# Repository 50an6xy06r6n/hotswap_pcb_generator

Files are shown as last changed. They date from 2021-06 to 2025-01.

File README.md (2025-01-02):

# 3D-Printable Hotswap Keyboard PCB Generator
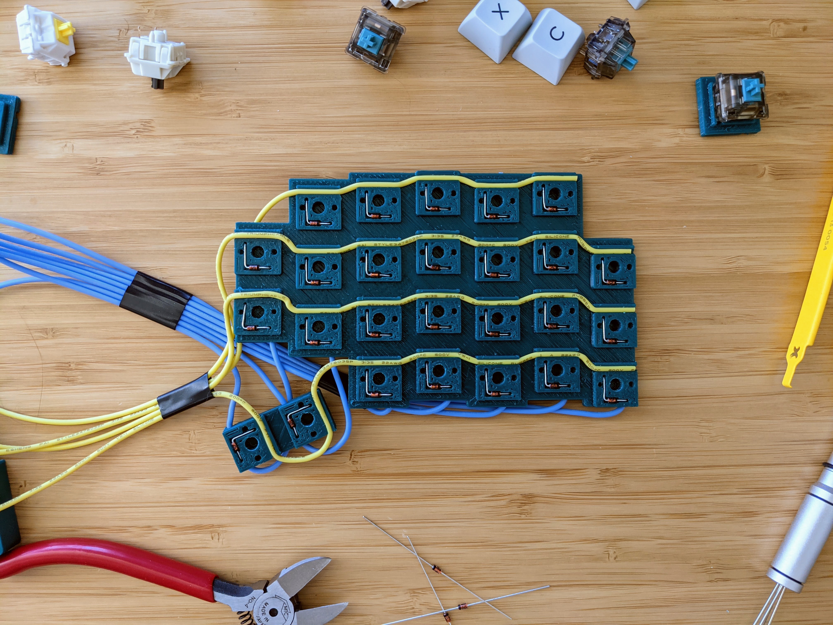
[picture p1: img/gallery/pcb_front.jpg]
Example PCB


This is an OpenSCAD script that can be used to generate 3D-printable hotswap "PCBs", plates, and cases for prototyping new keyboard layouts. I originally wrote this to help me prototype a split ergo layout without needing to solder/desolder all the switches every time. If you're only going to be building the keyboard once, this is probably a lot more work than just handwiring, but it might be useful if you're iterating on a design and want to reuse your switches easily. Currently supports MX and Kailh Choc v1 switches. If someone wants to send me low-profile Cherry switches, v2 Chocs, or Alps I can add those as well.

### Features
- Support for MX-style and Kailh Choc switches
- Automatically generate plates from the same layout data
- Generate cases with tenting options
- Integrate microcontrollers and TRRS sockets for a fully-functional keyboard
- Support for stabilizers
- Support for non-standard grid spacings

### Usage
The OpenSCAD script reads the layout data from the `layout.scad` header file, which you can either write by hand or generate from a KLE json file using the provided script (requires node.js 14+):
```
cd script/
npm install
npm start -- <layout json file>
```
Once the basic layout is set there are more values you can tweak in `layout.scad` to change the footprint of the PCB, add components like MCU/TRRS sockets, and add stabilizers/standoffs. Other parameters such as wire/pin diameters and pcb/plate thicknesses (and many many more) are contained in `parameters.scad`. All these values are described in full in the [`scad/` README](scad/README.md). [`default_layout.scad`](scad/default_layout.scad) contains an example layout that uses most of the available customizations, so you can see what's possible. The [`example_layouts/`](example_layouts) directory contains a couple of other examples as well, with varying degrees of complexity.

**Note on OpenSCAD:** I highly recommend installing [the nightly development build of OpenSCAD](https://openscad.org/downloads.html#snapshots), as it includes support for the [Manifold](https://github.com/elalish/manifold) geometry engine, which is much much faster than the CGAL library that OpenSCAD has historically used. Stuff that can take minutes to render with CGAL renders in seconds with Manifold enabled. It can be enabled in the nightly builds by going to Edit -> Preferences -> Features and checking the box for "manifold". While you're in there you might also want to enable "roof" as well, since it's used for some of the (experimental) chamfering options.

### Assembly
The [full build guide](guide/build_guide.md) goes into much more details and has pictures of the process, but here's how assembly works at a high level:

1. Use `pcb.scad` to generate an STL for 3D printing. Any print settings should work, though you may want to tweak the hole sizes depending on your printer's tolerances and desired fit tightness. A utility knife, and some drill bits may help with post-processing.

2. (Optional) If desired, you can use `case.scad`, `plate.scad`, and `backplate.scad` to generate a case.

3. Measure out and cut wires for the rows and columns, and press them into the corresponding channels in the PCB.

4. Bend your diodes and install them in the sockets. I designed this for glass 1N4148 diodes, though you can tweak the size of the diode cutout if the ones you have don't fit for some reason.

5. (Optional) Use a utility/craft knife to cut slits in the row wires where the switch pins go. The switch pins are usually sharp enough to pierce the insulation, but this makes switch installation more reliable.

6. At this point you have a completed PCB, and you can mount it to your plate and add switches and other components (as you would with any other PCB).

### Design Details
The design uses 22AWG stranded wire for the matrix rows and columns (wire gauge is configurable via `wire_diameter`), with the top switch pin plugging directly into the row wire and the diode cathode sticking through the column wire. The bottom switch pin makes contact with the diode anode, though that connection can be a bit finicky. I've solved this for now by putting a slight angle on the channel that holds the anode leg and switch pin, but it does slightly bend the switch pin in the process. The bend is pretty minor and can be easily bent back, but the angle is configurable via `diode_pin_angle` if you prefer not to have one. You can also use a bit of aluminum foil to solidify the contact point, but I found that to be too tedious in practice. There is an experimental setting for MX sockets that creates more reliable connections at the expense of more complexity when bending diodes. Electrical integrity is pretty good overall once the switches are properly seated. Hole sizes and such are tuned to my printer, which isn't the most dimensionally accurate, so you may get a better fit by tweaking the hole sizes slightly. I also recommend generating the final STL with a larger `$fn` value (the edge count for circles), though it does take a while to compile.

The basic layout format matches the commonly-used Keyboard Layout Editor (KLE) format, and the provided node.js script can convert a KLE json into an SCAD file that is included in the main script as a header. I originally wanted to use the OpenSCAD customizer to do this, but it turns out that doesn't support nested vectors at the moment. There are also a couple of additional parameters on each key in the `base_key_layout` array pertaining to the geometry of the PCB that you might want to change. One affects how much the PCB extends past each socket, which allows you to trim off excess on the edges and connect parts that are not directly adjacent (such as thumb clusters). Another allows you to rotate the wire channels for the column wires, which is also useful for wiring parts that don't follow a grid, like thumb clusters. This format is also used to position and configure all the other types of components you can add to your board. The [`scad/` README](scad/README.md) contains a full description of all of these options, and [`default_layout.scad`](scad/default_layout.scad) contains a comprehensive example that uses most of them.

### Additional Context
My original design was inspired by [stingray127's handwirehotswap project](https://github.com/stingray127/handwirehotswap), with the key difference being that I wanted to use stranded wire for the row contacts. That design worked pretty well, but I was using diode legs to connect the sockets vertically, and those connections turned out to be pretty flaky. In addition, there was nothing holding the sockets in place besides friction with the switch legs, and when seating switches you had to be pushing up on the socket from the back. I solved these problems by just using another set of wires for the columns and combining all the sockets into a solid plate.

After that I got some requests to add a plate generation feature, and I went overboard from there. Most of my personal development in the near future will probably be related to case generation, as I've personally settled on a layout I like and have had solderable PCBs made for.

### Gallery
Completed keyboard
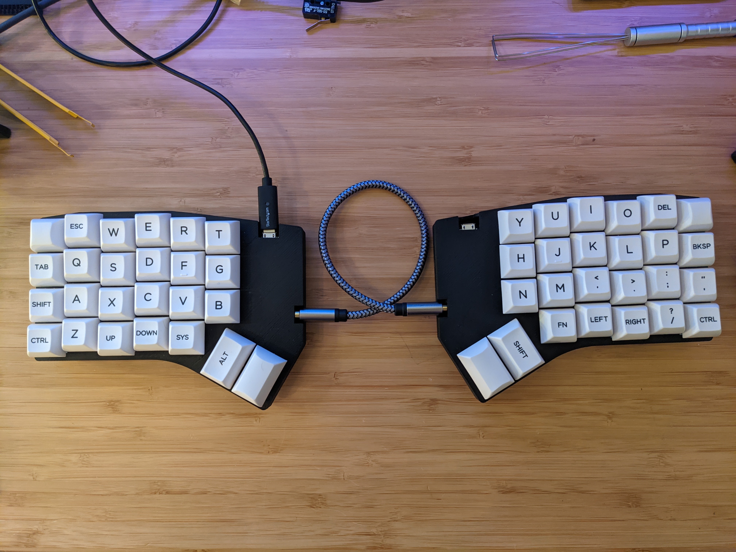
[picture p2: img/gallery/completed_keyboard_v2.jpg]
Completed keyboard v2


Bare split PCB
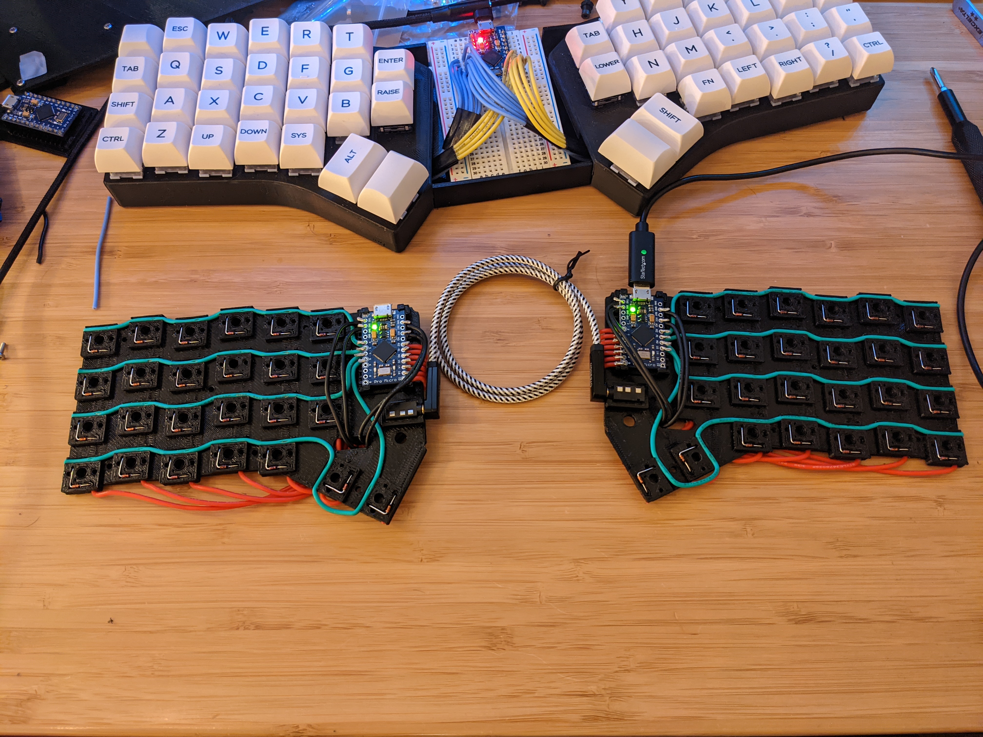
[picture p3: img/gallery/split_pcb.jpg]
Bare split PCB


Keyboard with tenting
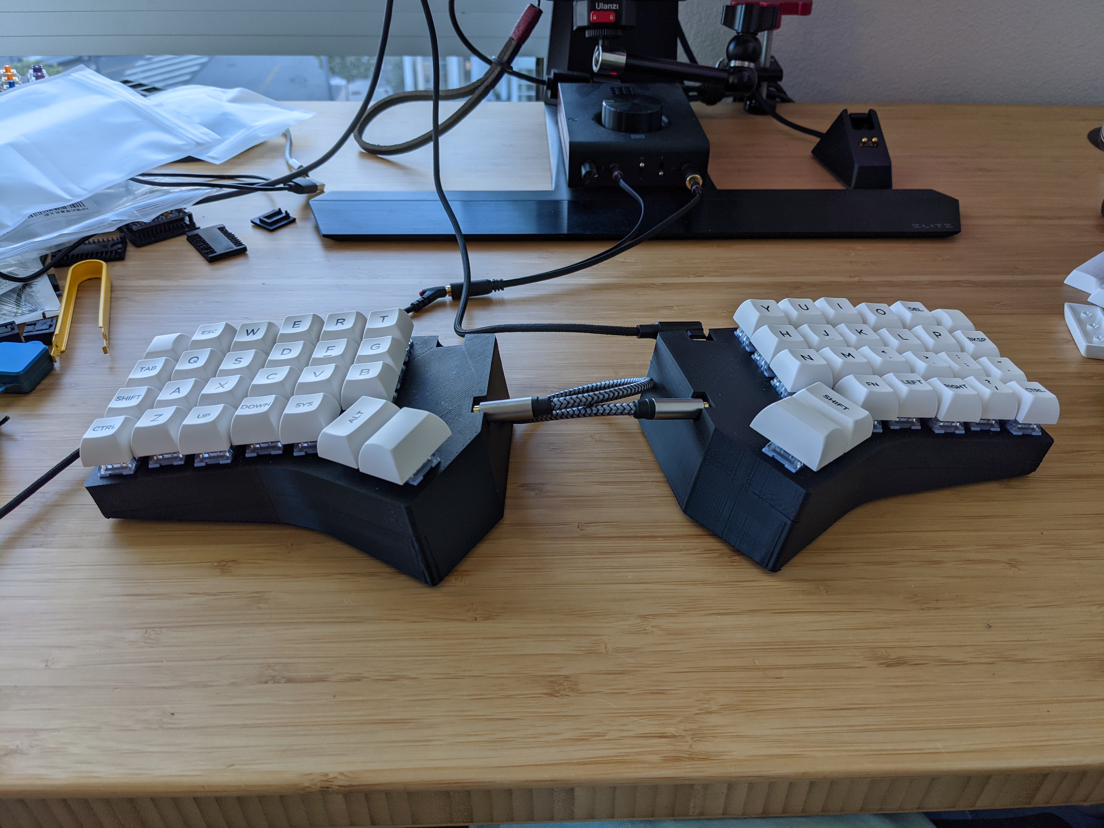
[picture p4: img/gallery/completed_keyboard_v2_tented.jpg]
Keyboard with tenting


Completed keyboard (v1, case designed in FreeCAD)
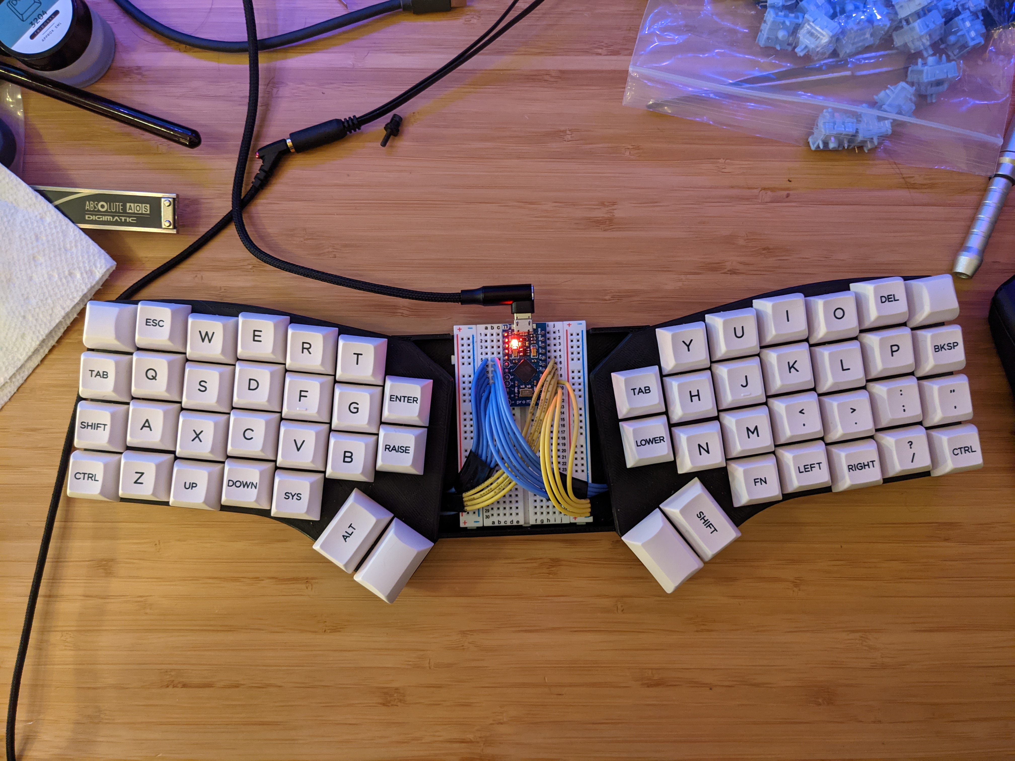
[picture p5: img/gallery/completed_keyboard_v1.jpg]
Completed keyboard v2


Back of the PCB (v1, disconnected thumb cluster)
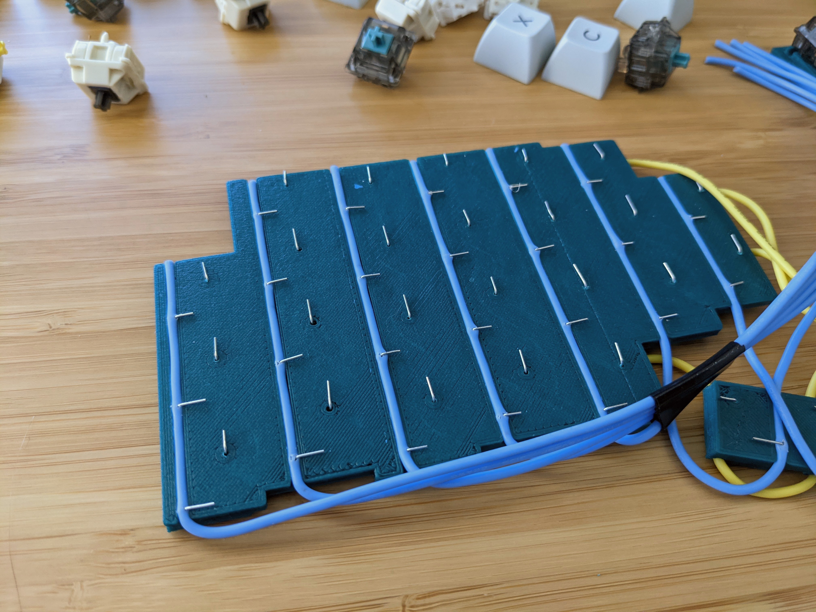
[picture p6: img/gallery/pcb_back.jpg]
Back of the PCB


OpenSCAD output (v1, no MCU or TRRS)
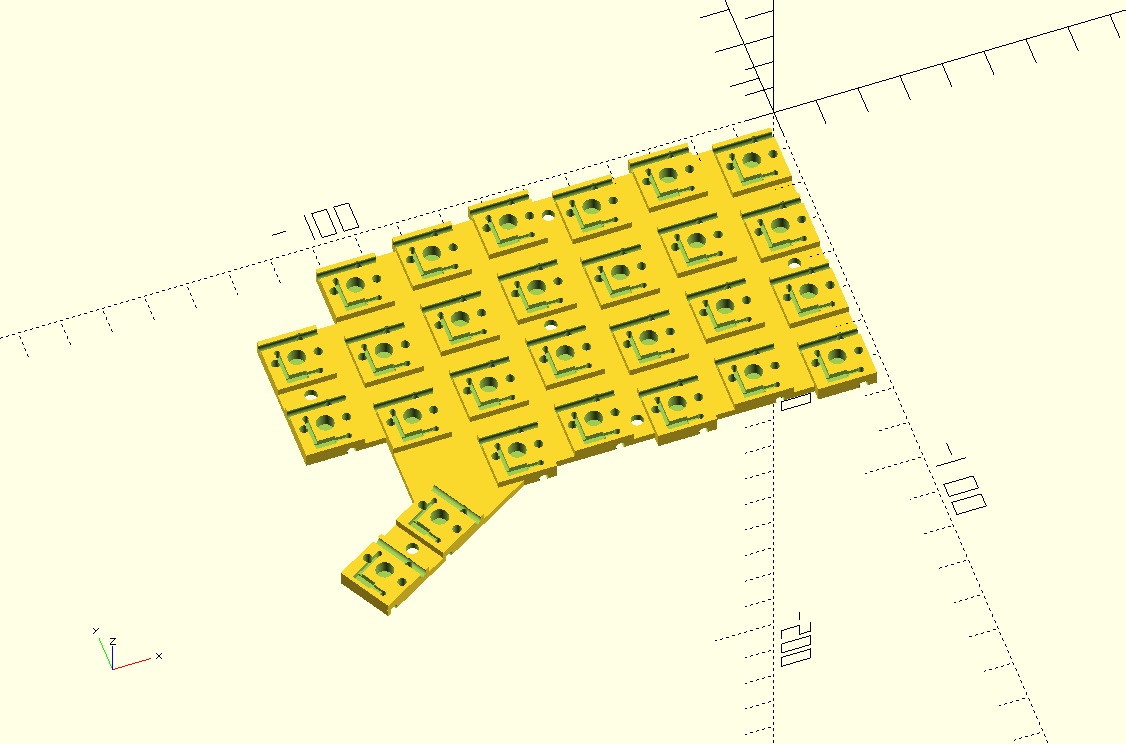
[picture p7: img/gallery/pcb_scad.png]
OpenSCAD output


Original design with separate sockets and no wire management
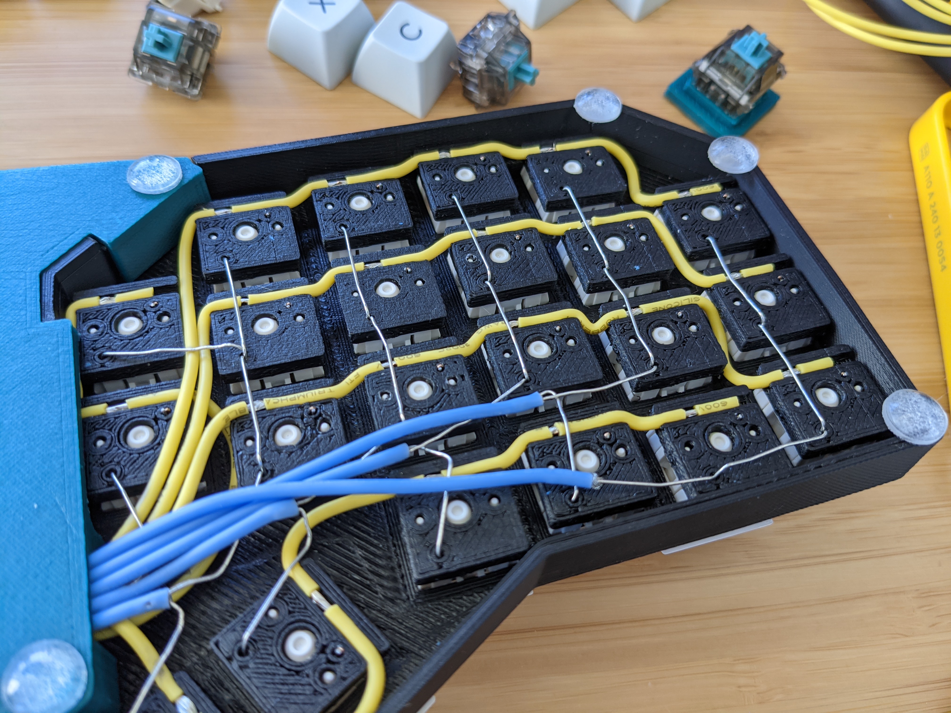
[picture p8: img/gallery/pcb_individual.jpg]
Original design


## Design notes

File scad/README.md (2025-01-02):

# OpenSCAD Source
`pcb.scad`, `case.scad`, `plate.scad`, and `backplate.scad` are the files responsible for generating the actual PCB, case, plate, and backplate STLs. `keyboard.scad` just combines all three relevant components so you can preview the final result before you print anything. There's also `diode_bending_template.scad`, which generates a small jig for bending the diode legs repeatably, though the STLs for these are already in the [`stl`](../stl) directory.

 General parameters for the PCB and plate come from `parameters.scad` and layout data comes from `layout.scad`. If you have a layout in KLE, you can use the [conversion script](../script) to generate a stub with the key positions converted. If `layout.scad` doesn't exist, layout data is taken from `default_layout.scad`, which contains default values (to avoid issues with undefined variables/modules).

 Below are descriptions of all the values that can be customized to suit your needs without breaking the code (I think). File an issue if a customization is broken or you have an idea for a feature.

### Layout Parameters:
| Name | Description | Location |
| ---- | --- | --- |
| `base_switch_layout` | Defines position, orientation, and size of each key socket, as well as the size of the border that connects each socket to adjacent ones. For each key, the layout looks like this: <pre>[<br/>&nbsp;&nbsp;[<br/>&nbsp;&nbsp;&nbsp;&nbsp;[x_location, y_location],<br/>&nbsp;&nbsp;&nbsp;&nbsp;key_size,<br/>&nbsp;&nbsp;&nbsp;&nbsp;[rotation, rotation_x, rotation_y]<br/>&nbsp;&nbsp;],<br/>&nbsp;&nbsp;[top_border, bottom_border, left_border, right_border],<br/>&nbsp;&nbsp;extra_data,<br/>&nbsp;&nbsp;[top_trim, bottom_trim, left_trim, right_trim]<br/>]</pre>All variables besides `x_location` and `y_location` are optional, though within each grouping values must be defined in order. For switches, border values define multiples of `border_width`, which is calculated from the difference between `socket_size` and `unit`. If you want to define the size of the border in mm, multiply by the `mm` variable, which does the conversion. If you have different vertical and horizontal spacing, use `h_mm` and `v_mm` instead. `extra_data` corresponds to the `rotate_column` parameter in the switch modules, which allows you to rotate the column wire channels for easier routing for things like thumb clusters. The `trim` parameters are used (if `use_plate_layout_only = true`) to indicate component edges that form hard outer boundaries of the plate. Anything that sticks out past that will be trimmed off. This can be useful when dealing with edges that meet at an external angle, where it may be hard to get borders to meet at a single point. | `layout.scad` |
| `base_mcu_layout` | Defines the position of an (optional) microcontroller daughterboard. Data format is identical to that of `base_switch_layout`, though `key_size` should be set to `mcu_h_unit_size`, which is the socket's width in key units calculated from `mcu_width` and `mcu_unit_resolution`. Border values are defined in mm. No `extra_data` is defined. | `layout.scad` |
| `base_trrs_layout` | Defines the position of an (optional) TRRS socket for a split layout. Data format is identical to that of `base_switch_layout`, with the socket pointing upwards. This allows the socket to be properly rotated when using the `invert_layout_flag`. Border values are defined in mm. No `extra_data` is defined. | `layout.scad` |
| `base_stab_layout` | Optional parameter that allows you to add stabilizer holes and cutouts to your PCB and plate/case. Data format is identical to that of `base_switch_layout`, where `extra_data` is a layout vector of the form `[key_size, left_offset, right_offset, switch_offset=0]`. Most of the stabilizer sizes you'll need are included in `stabilizer_spacing.scad`, and can be referenced by name (i.e. `2u`, `6_25u`, etc). You can usually add stabilizers to a key by copying its layout data, setting borders to `[1,1,1,1]`, and adding the `extra_data`. | `layout.scad` |
| `base_via_layout` | Defines the position of (optional) "vias" (i.e. holes) in the PCB that allow wires to be more cleanly routed from one side to the other. Data format is identical to that of `base_switch_layout`, with the via placed at the center of the key unit. Each via is an oblong hole constructed by hulling two cylinders. By default, via size is controlled by `via_width` and `via_length`, but this can be overridden for each via using `extra_data`. | `layout.scad` |
| `base_plate_layout` | Optional parameter that allows greater control when defining the shape of the plate and case. Unlike the other layout parameters, this is actually a vector of layouts in the `base_switch_layout` format. <br/><br/>If `use_plate_layout_only` is `false`, all elements in this parameter will be flattened and added to the hull used to define the plate shape (before the offset is applied). In this mode, it can be used to refine the overall shape of the plate, such as adding more room for longer modifier keys or squaring up the plate profile. <br/><br/>If `use_plate_layout_only` is `true`, then the plate shape is completely defined by `base_plate_layout`. In this mode, each layout within the vector is hulled individually, and the resulting shapes are unioned before the plate offset and fillets are applied. This mode can be used to create concave plate shapes not possible with simple hulling operations. `extra_data` for each element is a vector `[component_type, extra_extra_data]`, where `component_type` is selected from `["switch", "mcu", "trrs", "stab"]`, and `extra_extra_data` is anything you want passed down to the component's plate footprint extra data (currently only relevant for stabilizers). "switch" is the default. Since this mode requires all key positions to be copied, I've provided a `slice()` helper that can be used to partially copy the existing switch layout. See `default_layout.scad` for an example of this usage mode. | `layout.scad` |
| `base_standoff_layout` | Defines the position of each (optional) standoff. Data format is identical to that of `base_switch_layout`, with the standoff placed at the center of the key unit. This makes it means that you can place a standoff in between two keys by just averaging their positions. By default, standoffs are configured according to the `standoff_integration_default` and `standoff_attachment_default` parameters defined in `parameters.scad`, but these can be overridden on a per-standoff basis using the `extra_data` parameter. | `layout.scad` |
| `additional_plate_cutouts()` | Unlike most of the other parameters, this is a module, not a variable. You can use it to define custom cutouts in the plate (also applies to cases). Use `position_item()` from `utils.scad` to help place the cutouts relative to existing components. The sample `eggcat.scad` uses this to create a large cutout above the MCU and TRRS. | `layout.scad` |
| `additional_case_cavities()` | This is another module parameter. You can use it to add to the internal case cavity to accommodate wire routing, batteries, etc. Use `position_item()` from `utils.scad` to help place the cutouts relative to existing components. The sample `eggcat.scad` uses this to create a relief on one side of the case that's used for wire routing off the MCU. | `layout.scad` |
| `backplate_cutouts()` | This is another module parameter. You can use it to add pockets and cutouts to the bottom of the backplate (useful for positioning bumpons and mounting hardware). Use `project_onto_plane()` from `utils.scad` to help place the cutouts relative to existing components. This will account for the tent angle of your backplate and ensure that the feature is still positioned according to the x-y coordinates of the main layout. The sample `eggcat.scad` uses this to create pockets for bumpons and a magsafe adapter ring. | `layout.scad` |
| `use_plate_layout_only` | Changes the way the plate profile is generated. For more details, see `base_plate_layout`. | `layout.scad` |
| `invert_layout_flag` | If set to true, the layout will be inverted when generating the PCB and plate. This is handy for split layouts with identical left and right hands, as it saves you the trouble of copying over any changes you make to the borders and standoff positions. | `layout.scad` |
| `layout_type` | This can be set to either `column` or `row` (depending on the layout stagger), and affects which side the recessed grid is printed on, which is necessary for routing matrix wires that don't run in a straight line. For row-staggered layouts, the grid will be on the bottom (column-side) of the PCB, so it will be easier to print upside down. | `layout.scad` |
| `tent_angle_x` | Angle at which the keyboard is tilted around the x-axis. | `layout.scad` |
| `tent_angle_y` | Angle at which the keyboard is tilted around the y-axis. | `layout.scad` |
| `tent_point` | Point around which the keyboard is tented. This is the point that will stay at 0 elevation above the desk. Useful for positive typing angles. | `layout.scad` |

### PCB Parameters:
| Name | Description | Location |
| ---- | --- | --- |
| `wire_diameter` | The diameter of wire (in mm) used for the matrix. The default value of 2.15 works for 22AWG silicone-sleeved wire, which is what I used, but it can be tweaked based on your fit preferences or a different kind of wire. | `parameters.scad` |
| `diode_pin_angle` | This changes the angle of the channel that forms the bottom switch pin socket. The bottom switch pin makes contact the diode anode leg, and the connection can sometimes be a bit flaky. Slightly angling the channel upwards forces the switch pin into the diode leg as it's inserted, and makes for a more robust connection. This can put a slight bend in the switch pin that can be easily bent back (the bottom pin tends to be the sturdier of the two), but if you don't want that you can set the angle to 0. | `parameters.scad` |
| `diode_foldover` | Length that the diode folds over on the back of the PCB. Only applies when `use_folded_contact = true` | `parameters.scad` |
| `pcb_thickness` | Defines the overall thickness of the PCB. This must be at least 4mm, which is the minimum needed to fit both row and column wires. Can be increased if you want a sturdier PCB. | `parameters.scad` |
| `pcb_type` | If you decide to have a traditional PCB fabricated for your board, you can change this from `printed` to `traditional` to help convert your existing case. Currently it just adjusts the height of the plate-to-PCB standoffs, since a traditional PCB won't have the step between the base of the socket and the wire routing area. | `parameters.scad` |
| `teardrop_overhang_angle` |  Angle of the teardrop part of the wire channel. Turns the top part of the channel circle into a triangle, for clean printing. Set to the minimum angle your printer can print clean overhangs. Default of 45 is fine for most printers. | `parameters.scad` |

### Switch Parameters:
| Name | Description | Location |
| ---- | --- | --- |
| `switch_type` | This can be set to either `mx` or `choc`, depending on the type of switch you plan to use. This changes the PCB cutouts, as well as the plate thickness and spacing used for standoffs. Support for other switch types is possible if I'm able to obtain them. | `parameters.scad` |
| `switch_orientation` | This can be set to either `north` or `south`, and defines the LED orientation of the switch. South-facing offers better compatibility with Cherry-profile keycaps, while north-facing may result in better illumination of shine-through legends (though there is not yet support for LEDs). | `parameters.scad` |
| `five_pin_switch` | Sets whether to print the two side holes for the extra stability pins of a 5-pin switch. `true` fits 3 and 5 pin switches, `false` is cleaner and may be marginally faster to print. | `parameters.scad` |
| `use_folded_contact` | This generates an experimental socket for MX switches that provides more robust hotswap contacts at the expense of more complexity when bending diodes. | `parameters.scad` |
| `row_wire_contact_angle` | This sets the angle that the row wire crosses over the top switch pin at, to improve contact between the sharp pin and the wires. The angle is the deviation from straight. Probably best not to go above 25 or below -20, unless you don't mind holes in walls. A larger angle may require cutting a larger hole in the wire casing. For choc switches, smaller may be necessary for there to be room for the deviation to return to straight. | `parameters.scad` |

### Stabilizer Parameters:
| Name | Description | Location |
| ---- | --- | --- |
| `stabilizer_type` | This can be set to either `pcb` or `plate`. The plate cutouts for both are the same, and the only difference is that `pcb` adds holes in the PCB, so I recommend just always using `pcb`. | `parameters.scad` |

### Case Parameters:
| Name | Description | Location |
| ---- | --- | --- |
| `case_type` | This can be set to `sandwich`, `plate_case`, or `backplate_case`, and defines the structure of the optional case. `sandwich` is the most basic, and consists of a switch plate, PCB, and backplate connected by standoffs. `plate_case` is an integrated-plate case, where the sides are enclosed by a wall connected to the plate. The backplate is slightly inset into the case. `backplate_case` is currently unimplemented, but will likely be some kind of tray-mount case. | `parameters.scad` |
| `case_wall_thickness` | Thickness of the case wall at the point where it meets the plate (before chamfering). Default value of 2 is the minimum recommended thickness. | `parameters.scad` |
| `case_wall_draft_angle` | Angle at which the case walls slope outwards from the plate. Corners are rounded. Angle measured from vertical. | `parameters.scad` |
| `case_chamfer_width` | Width of the chamfer on the top of the case, measured horizontally from the unchamfered plate edge to the chamfered plate edge. Corners are rounded. | `parameters.scad` |
| `case_chamfer_angle` | Angle (from horizontal) of the chamfer on the top of the case. Corners are rounded. Angle measured from horizontal. | `parameters.scad` |
| `chamfer_corner_type` (experimental) | This defines how the chamfers and drafted walls behave at corners. Possible values are `rounded` (default), `straight` (experiment), and `beveled` (extra-experimental). Some notes:<br/>&nbsp;&nbsp;1. `straight` and `beveled` require a nightly build of OpenSCAD, as they use the experimental `roof()` module.<br/>&nbsp;&nbsp;2. `straight` and `beveled` are also not compatible with external fillets, as that usually causes `roof()` to generate non-manifold geometry for some reason. | `parameters.scad` |
| `case_base_height` | Height of the vertical portion of the case wall at its base. Only applies when a draft angle is applied to the case wall. Does not include the height of the backplate flange. | `parameters.scad` |
| `case_fit_tolerance` | Fit tolerance between interlocking case parts (e.g. an integrated-plate case and its backplate), so that they can be easily taken apart when unscrewed. Default value of 0.2 creates a pretty snug fit that doesn't get stuck. | `parameters.scad` |

### Plate Parameters:
| Name | Description | Location |
| ---- | --- | --- |
| `plate_margin` | Defines how far the plate sticks out beyond the PCB. If you wish to have more granular control over the plate shape, you can set this to 0 and generate a separate layout for the plate and edit the borders directly. | `parameters.scad` |
| `plate_outer_fillet` | Radius of outer fillets on the plate. | `parameters.scad` |
| `plate_inner_fillet` | Radius of inner fillets on the plate. Can be set large for nice curves on thumb cluster connections, for example. | `parameters.scad` |
| `plate_precision` | **[DEPRECATED - You should use the `trim` parameter in the layout section to fix this issue]** Approximate point precision (in mm) of the basic plate outline. This setting allows vertices placed near enough each other to be merged when using the plate layout override. Since not all the elements are hulled, adjacent elements that are angled with each other and meet at a point (such as in a thumb cluster) may not meet exactly at a point, creating a weird jagged edge when the plate offset is applied. The default layout has an example of this where the thumb cluster meets the footprint of the TRRS socket. The default value of 1/100 is a good balance of usability and precision, but if you're having trouble getting rid of the jagged edges you can lower it. | `parameters.scad` |

### Backplate Parameters:
| Name | Description | Location |
| ---- | --- | --- |
| `backplate_thickness` | Defines the thickness of the backplate. | `parameters.scad` |
| `backplate_index_height` | If using the `plate_case` case type, this defines the height of the feature that indexes into the bottom of the case. | `parameters.scad` |
| `backplate_lip_width` | If using the `plate_case` case type, this defines the width of the feature that indexes into the bottom of the case. If set to `undef` it becomes a solid area. | `parameters.scad` |
| `backplate_screw_flange_thickness` | Defines the thickness of the material that backplate standoff screws clamp onto (i.e. thickness - counterbore depth). | `parameters.scad` |
| `pcb_backplate_spacing` | Defines the distance between the bottom of the PCB and the top of the backplate. Can be decreased for a lower profile or increased for more room to route wires. | `parameters.scad` |

### MCU Parameters:
| Name | Description | Location |
| ---- | --- | --- |
| `mcu_type` | This can be set to `bare` or `socketed`, depending on whether your MCU has pins soldered into it. Bare MCUs are a little easier to wire up and are lower-profile. Socketed MCUs are a little more tricky to wire and stick up more, but if you have an MCU salvaged from a previous build it's likely to have the pins already soldered in. | `parameters.scad` |
| `mcu_width` | Width of the daughterboard PCB in mm. Default value of 18 works for Pro Micro footprint. | `parameters.scad` |
| `mcu_length` | Length of the daughterboard PCB in mm. Default value of 33 works for Pro Micro footprint. | `parameters.scad` |
| `mcu_height` | Distance from the top of the daughterboard PCB to the base of the header pins in mm. Default value of 4.25 works for Pro Micro footprint on generic square header pins. Only relevant for socketed MCUs. | `parameters.scad` |
| `mcu_row_spacing` | Center-to-center distance between rows of pins in mm. Default value of 15.24 (0.6 inches) works for Pro Micro footprint. | `parameters.scad` |
| `mcu_row_count` | Number of pin rows. Currently can't be changed from the default value of 2, as I don't know of any boards like that, and it would make the code very complicated. | `parameters.scad` |
| `mcu_pin_count` | Total number of pins on the daughterboard. Default value of 24 works for Pro Micro footprint. | `parameters.scad` |
| `mcu_pin_pitch` | Center-to-center distance between adjacent pins in mm. Default value of 2.54 (0.1 inches) is pretty standard and works for Pro Micro footprint. | `parameters.scad` |
| `mcu_pin_offset` | Offset from the rear of the daughterboard to the boundary of the nearest pin. Default of value of 0 works for Pro Micro footprint, and any other board where the pins extend all the way to the back of the board. | `parameters.scad` |
| `mcu_connector_width` | Width of the daughterboard connector (for making plate cutouts) in mm. Default value of 13 works for Micro-USB and USB-C connectors. May not be necessary for mid-mount connectors that don't stick very far above the board (i.e. Elite-C). | `parameters.scad` |
| `mcu_connector_length` | Length that the daughterboard connector extends into the board (for making plate cutouts) in mm. Default value of 4 works for Micro-USB and USB-C connectors. May not be necessary for mid-mount connectors that don't stick very far above the board (i.e. Elite-C). | `parameters.scad` |
| `mcu_connector_height` | Height of the connector plug you intend to use in mm, for plate/case cutouts. Default value of 8 should cover most Micro-USB and USB-C cables. | `parameters.scad` |
| `mcu_connector_offset` | Distance between the center plane of the daughterboard connector and the center plane of the daughterboard PCB in mm, used for making accurate case cutouts. Default value of 2 works for Pro Micro. | `parameters.scad` |
| `mcu_pcb_thickness` | Thickness of the daughterboard PCB. Default value of 1.6 is pretty standard. | `parameters.scad` |
| `mcu_socket_width` | Width of the socket holding the MCU. Default value of `mcu_width + 4` works pretty well. | `parameters.scad` |
| `mcu_socket_length` | Length of the socket holding the MCU. Default value of `mcu_length + 4` works pretty well. | `parameters.scad` |
| `expose_mcu` | Experimental feature to create a cutout in the plate above the MCU, to allow status lights to be seen and/or pins to be accessed. Also looks cool maybe? | `parameters.scad` |

### TRRS Parameters:
| Name | Description | Location |
| ---- | --- | --- |
| `trrs_width` | Width of the TRRS socket in mm. Default value of 6 works for the popular PJ-320A socket. | `parameters.scad` |
| `trrs_length` | Length of the TRRS socket in mm (not including the round flange). Default value of 12.1 works for the popular PJ-320A socket. | `parameters.scad` |
| `trrs_height` | Height of the TRRS socket in mm. Default value of 5 works for the popular PJ-320A socket. | `parameters.scad` |
| `trrs_flange_length` | Length of the round flange (where the plug inserts) in mm. Default value of 2 works for the popular PJ-320A socket. | `parameters.scad` |
| `trrs_flange_diameter` | Diameter of the round flange (where the plug inserts) in mm. Default value of 5 works for the popular PJ-320A socket (though this may vary slightly by manufacturer). | `parameters.scad` |
| `trrs_pin_spacing` | Distance between the two rows of pins in mm. Default value of 4.4 works for the popular PJ-320A socket. | `parameters.scad` |
| `trrs_nub_diameter` | Diameter of the little plastic locating nubs at the bottom of the socket in mm. Default value of 1.5 works for the popular PJ-320A socket. | `parameters.scad` |
| `trrs_nub_height` | Height of the little plastic locating nubs at the bottom of the socket in mm. Default value of 1 works for the popular PJ-320A socket. | `parameters.scad` |
| `trrs_nub_spacing` | Space between the little plastic locating nubs at the bottom of the socket in mm. Default value of 7 works for the popular PJ-320A socket. | `parameters.scad` |
| `trrs_nub_offset` | Offset between the front of the socket and the closest locating nub in mm. Default value of 1.5 works for the popular PJ-320A socket. | `parameters.scad` |
| `trrs_plug_width` | Width of the TRRS plug being used, for plate/case cutouts. | `parameters.scad` |

### Via Parameters:
| Name | Description | Location |
| ---- | --- | --- |
| `via_width` | Width of the via (also the diameter of the rounded end). This can be overridden for an individual via via `extra_data`. | `parameters.scad` |
| `via_length` | Total length of the via (including the rounded ends). This can be overridden for an individual via via `extra_data`. | `parameters.scad` |

### Standoff Parameters:
| Name | Description | Location |
| ---- | --- | --- |
| `standoff_integration_default`,<br>`standoff_attachment_default` | These two parameters define what component standoffs are integrated with and screwed into by default. Individual standoffs can overridde these values via `extra_data`. `standoff_integration_default` can be selected from the set `[plate, backplate, pcb, separate, none]`, while `standoff_attachment_default` comes from the set `[plate, backplate, pcb, plate_backplate, none]`.However, not all combinations are valid. For example, the two parameters cannot be the same (except for `none`), and the `plate_backplate` attachment parameter only works with `separate` standoffs. `separate` standoffs also can't have the `pcb` attachment, as they are attached to the PCB by default, and the parameter specifies the other component they're attached to. | `parameters.scad` |
| `standoff_diameter` | Defines the diameter of generated standoffs. Values greater than 5mm may interfere with plate cutouts if placed between keys. Default value is set for M2 screws. | `parameters.scad` |
| `standoff_clearance_hole_diameter` | Defines the size of through holes for standoff screws. Default value is set for M2 screws. | `parameters.scad` |
| `standoff_pilot_hole_diameter` | Defines the size of pilot holes for standoff screws. This diameter should be sized such that the screw can cut threads into the plastic. Default value is set for M2 screws. | `parameters.scad` |
| `standoff_counterbore_diameter` | Defines the size of counterbore holes for standoff screw heads. Useful for tented baseplates, and other instances where you want the screws to be recessed. Default value is set for M2 screws. | `parameters.scad` |
| `default_standoff_fillet` | Defines the radius of the default fillet applied to the base of standoffs. This can be overridden in the layout on a per-standoff basis. | `parameters.scad` |

### Cutout Grid Parameters:
| `cutout_grid_size` | Size of the holes in the grid cutout pattern. What that means exactly depends on the pattern. | `parameters.scad` |
| `cutout_grid_spacing` | Space between holes in the grid cutout pattern. Can also be thought of as the width of the lines in the mesh. | `parameters.scad` |

### Misc Parameters:
| Name | Description | Location |
| ---- | --- | --- |
| `fit_tolerance` | This can be used to compensate for vertical print tolerances between the standoffs and the PCB/plate that place them too far apart. Should only be a couple tenths of a millimeter at most. | `parameters.scad` |
| `$fn` | This defines the resolution of generated circles. When previewing, this is set to 12 for quick rendering. When generating final STLs, it's set to 60 for more accurate hole shapes. You can tweak these parameters as needed. | `parameters.scad` |

### Advanced Parameters
| Name | Description | Location |
| ---- | --- | --- |
| `unit` | Defines the size of "1U" in the layout. | `parameters.scad` |
| `h_unit` | Defines the size of "1U" horizontally. By default this is set to `unit`, but can be changed independently. (e.g. horizontal spacing for Choc keycaps is 18mm) | `parameters.scad` |
| `v_unit` | Defines the size of "1U" vertically. By default this is set to `unit`, but can be changed independently. (e.g. vertical spacing for Choc keycaps is 17mm) | `parameters.scad` |
| `mx_schematic_unit` | Defines the size of the grid used for positioning elements in the MX switch footprint. Shouldn't need to be changed. | `parameters.scad` |
| `socket_size` | Size of the socket footprint for the switch. Shouldn't need to be changed. | `parameters.scad` |
| `socket_depth` | Depth of the holes in the PCB for the switch pins and legs (in mm). 3.5mm should be enough for all the common switch types, but you can increase it if you're hitting the bottom for some reason. Note that this will create more perimeters and increase print time. | `parameters.scad` |
| `plate_thickness` | Defines the thickness of the plate. This is already set for both MX and Choc switches, but can be tweaked for tighter/looser fits or to compensate for print tolerances. Note that these are not multiples of 0.2mm, so if you're printing at a 0.2mm layer height you should set a 0.3mm first layer height for accurate results. | `parameters.scad` |
| `plate_cutout_size` | Defines the size of the plate cutouts. This can be adjusted to compensate for print tolerances or for a tighter/looser fit. | `parameters.scad` |
| `pcb_plate_spacing` | Defines the distance between the PCB and plate (used to calculate standoff length). This is predefined for MX and Choc switches. If you find that the spacing is slightly off, I recommend tweaking the `fit_tolerance` parameter first. | `parameters.scad` |
| `mcu_unit_resolution` | Size of the grid to align the MCU footprint size to (done for ease of layout positioning). Default value of 0.5 seems to work pretty well for the Pro Micro. | `parameters.scad` |

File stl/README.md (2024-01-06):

# STLs
Some pre-generated STLs to give you an idea of what the output looks like, as well as to let you test the fit of your components before you print a full PCB.

### `default_layout`
Contains STLs generated from `default_layout.scad`, which is the left side of a 4x6 split layout I designed. Includes a PCB and 3 kinds of cases. The first is a basic sandwich case with a plate and backplate attached with standoffs. The second is a slab case in the same profile as the sandwich case. The third is a chamfered and sloped case in a chunkier layout with no concavities in the profile.

### `diode_bending_template`
Contains STLs for all 3 types of diode bending templates.

### `individual_components`
Contains single instances of each of the sockets that interfaces with an external component. You can print them to test the fit with your printer's settings and tolerances and adjust the parameters before you spend time printing a full PCB.

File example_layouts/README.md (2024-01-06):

# Example Layouts
Just a few example layouts, each with a KLE json, the corresponding SCAD file, and a license, if applicable. The JD40 layout is straight out of the conversion script, but for some of the others (i.e. crkbd) I've made them a little prettier by doing stuff like connecting thumb clusters and adding standoffs. Hopefully this can give an idea of what's possible.

Note that third-party layouts included here may be subject to their own licenses/copyrights. Though it's a bit unclear whether they actually apply to any files created using them, they are included for completeness.

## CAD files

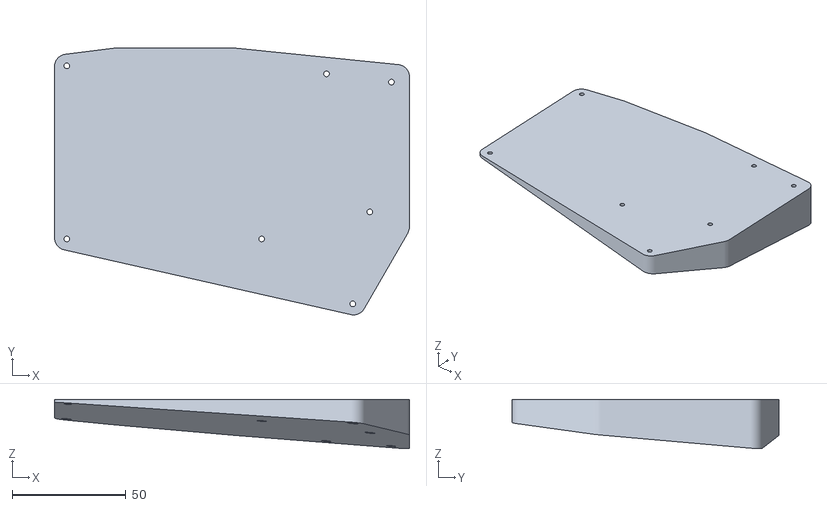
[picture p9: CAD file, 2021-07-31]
stl/default_layout/chamfered_case/backplate_tented.stl
156.2 x 117.4 x 21.7

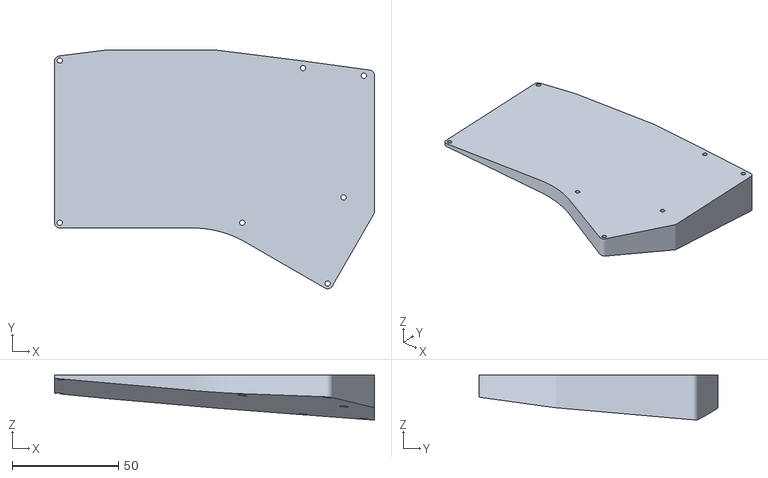
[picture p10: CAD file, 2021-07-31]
stl/default_layout/contoured_case/backplate_tented.stl
150.4 x 112.1 x 21.1

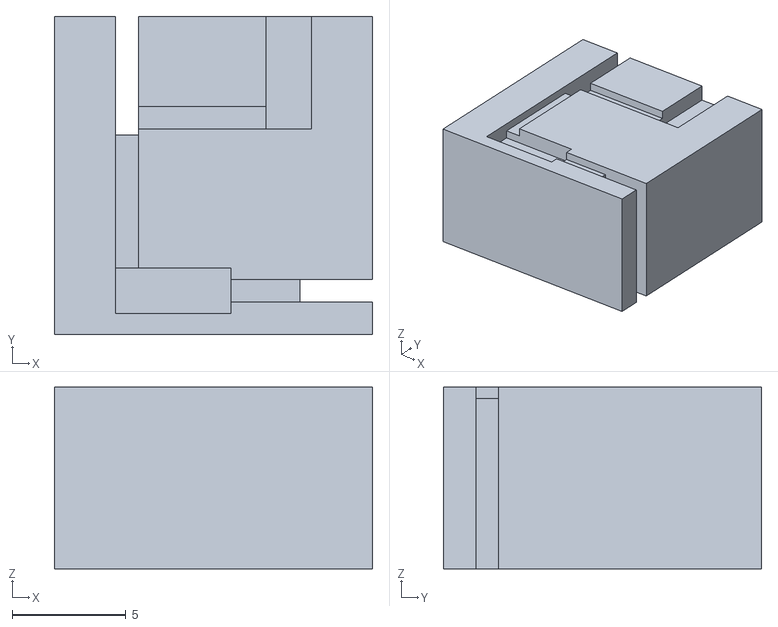
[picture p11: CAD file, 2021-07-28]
stl/diode_bending_templates/mx_improved_diode_bending_template.stl
14.0 x 14.0 x 8.00

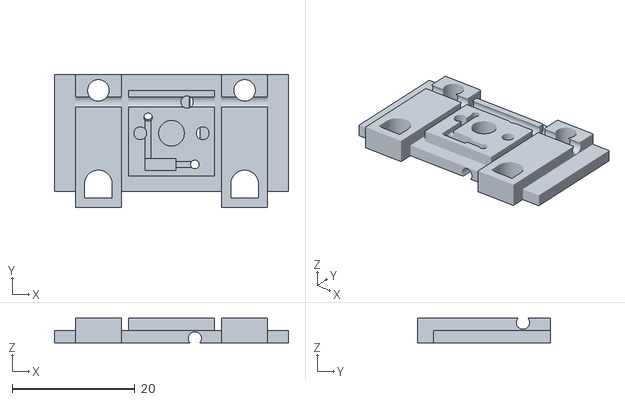
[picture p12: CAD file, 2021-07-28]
stl/individual_components/stabilizer_2u_pcb.stl
38.1 x 21.6 x 4.00

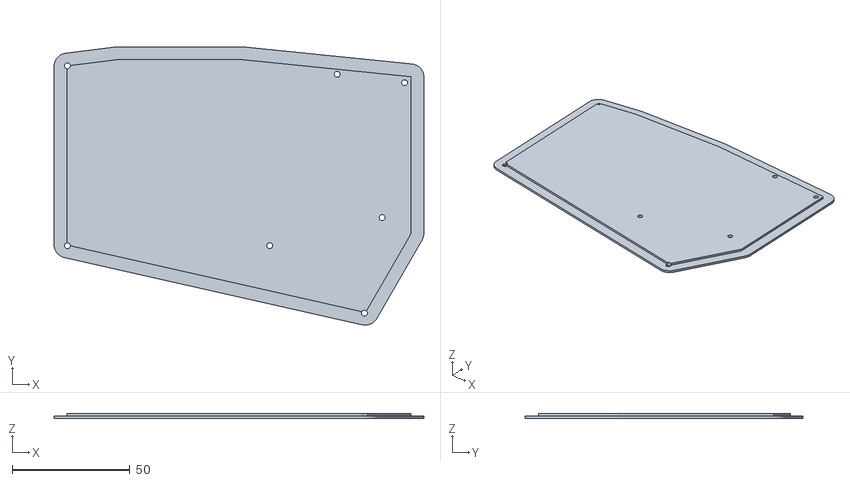
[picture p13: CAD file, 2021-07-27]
stl/default_layout/chamfered_case/backplate.stl
156.8 x 118.0 x 2.00

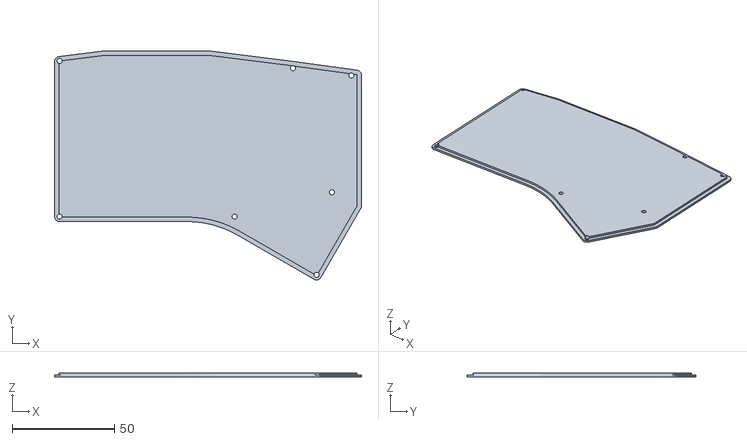
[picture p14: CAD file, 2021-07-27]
stl/default_layout/contoured_case/backplate.stl
150.4 x 112.1 x 2.00

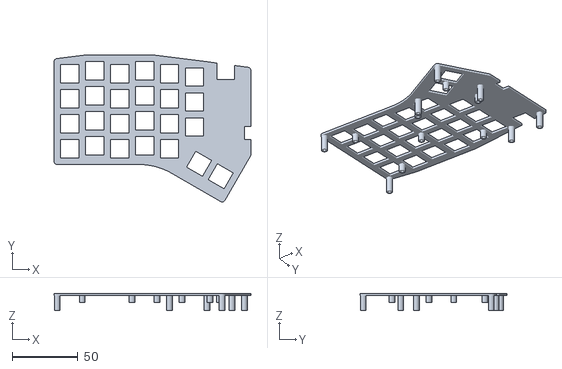
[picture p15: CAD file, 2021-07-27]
stl/default_layout/sandwich_case/plate.stl
150.4 x 112.1 x 13.0

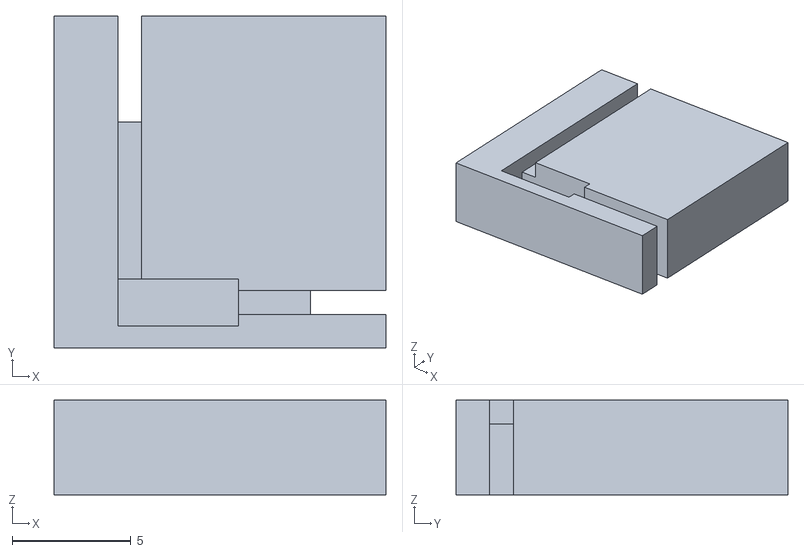
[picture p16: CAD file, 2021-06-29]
stl/diode_bending_templates/mx_diode_bending_template.stl
14.0 x 14.0 x 4.00

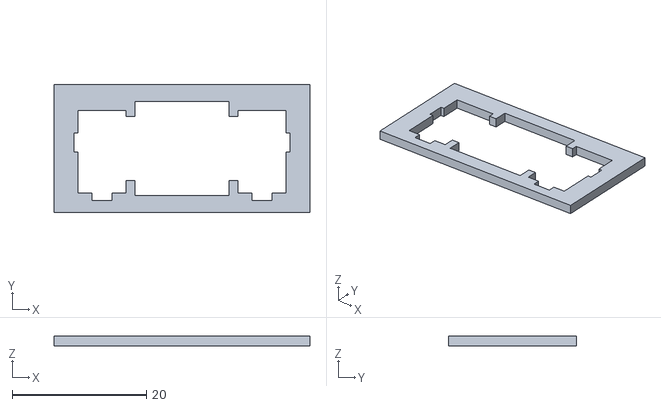
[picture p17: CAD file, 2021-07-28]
stl/individual_components/stabilizer_2u_plate.stl
38.1 x 19.1 x 1.50

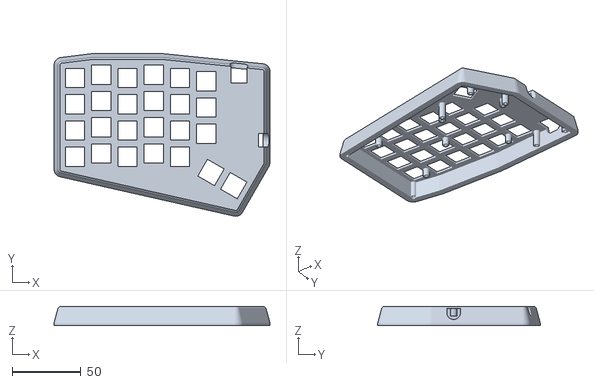
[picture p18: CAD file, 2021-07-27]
stl/default_layout/chamfered_case/case.stl
156.8 x 118.0 x 14.0

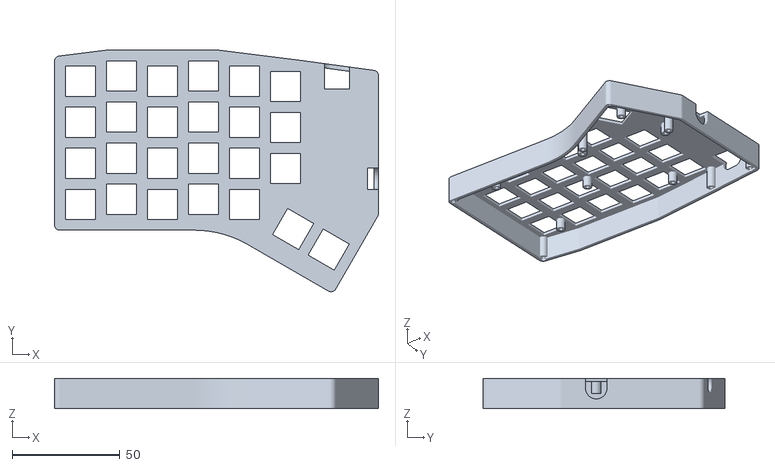
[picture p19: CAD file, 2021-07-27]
stl/default_layout/contoured_case/case.stl
150.4 x 112.1 x 14.0

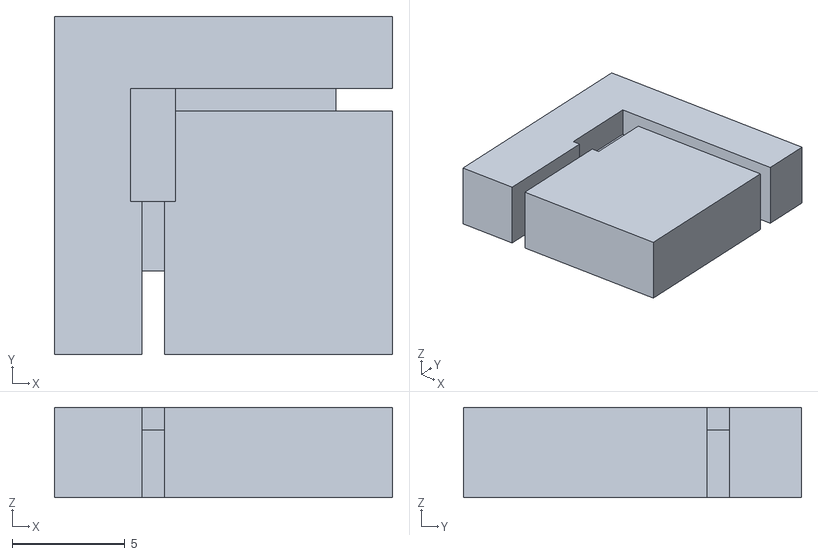
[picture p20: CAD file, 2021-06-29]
stl/diode_bending_templates/choc_diode_bending_template.stl
15.0 x 15.0 x 4.00

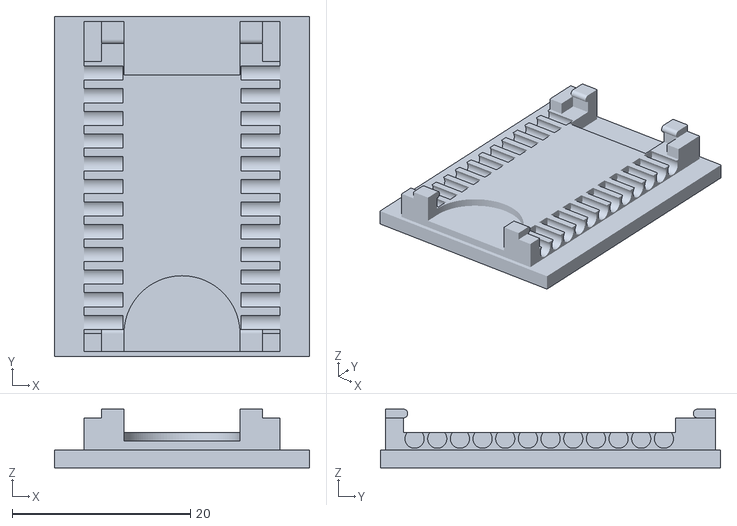
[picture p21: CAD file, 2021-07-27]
stl/individual_components/bare_mcu.stl
28.6 x 38.1 x 6.60

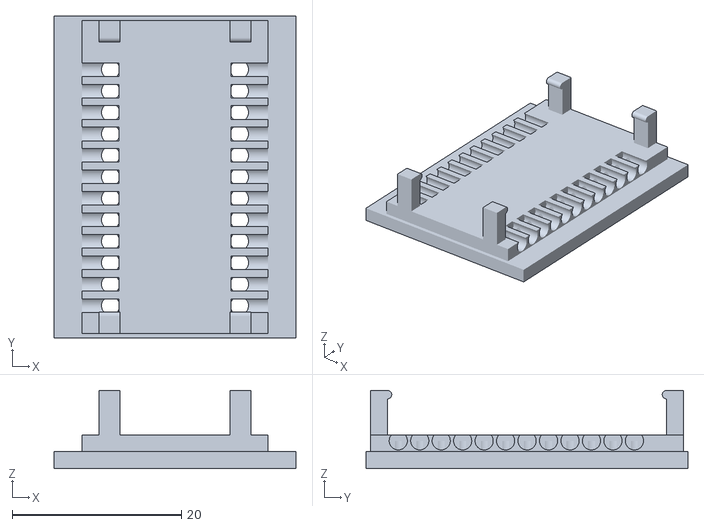
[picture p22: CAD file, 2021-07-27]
stl/individual_components/socketed_mcu.stl
28.6 x 38.1 x 9.25

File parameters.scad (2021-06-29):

/* [PCB Properties] */
// Diameter of row/column wire channels
wire_diameter = 2.15;
// Upward angle of switch pin in contact with diode anode (gives more reliable
// connections but slightly deforms pin)
diode_pin_angle = 5;  // [0:15]
// Switch type
switch_type = "mx";  // [mx, choc]
// Switch orientation (based on LED location)
switch_orientation = "south";  // [north, south]
// Standoff configuration
standoff_type = "plate";  // [plate, pcb, separate, none]
// Diameter of integrated standoffs
standoff_diameter = 4;
// Diameter of standoff clearance hole
standoff_clearance_hole_diameter = 2.5;
// Diameter of standoff pilot hole
standoff_pilot_hole_diameter = 1.6;
// Overall thickness of PCB
pcb_thickness = 4;
// Distance the plate sticks out past the PCB
plate_margin = 5;

/* [Advanced Values (related to switch size)] */
// Switch spacing distance
unit = 19.05;
// Horizontal unit size (18mm for choc keycaps)
h_unit = unit;
// Vertical unit size (17mm for choc keycaps)
v_unit = unit;
// Size of socket body
socket_size = 
    switch_type == "mx"
    ? 14
    : switch_type == "choc"
        ? 15
        : assert(false, "switch_type is invalid");
// Depth of the socket holes
socket_depth = 3.5;
// Thickness of the plate
plate_thickness = 
    switch_type == "mx"
    ? 1.5
    : switch_type == "choc"
        ? 1.3
        : assert(false, "switch_type is invalid");
// Size of the plate cutout
plate_cutout_size = 
    switch_type == "mx"
    ? 14
    : switch_type == "choc"
        ? 13.8
        : assert(false, "switch_type is invalid");
// Spacing between the top of the PCB and top of the plate
pcb_plate_spacing = 
    switch_type == "mx"
    ? 5
    : switch_type == "choc"
        ? 2.2
        : assert(false, "switch_type is invalid");
// Increase this if your standoffs are a bit too long due to printing tolerances
fit_tolerance = 0;
// Spacing of grid for pins
grid = 1.27;
// Resolution of holes (affects render times)
$fn=12;

module __Customizer_Limit__ () {}

// Thickness of a border unit around the socket (for joining adjacent sockets)
border_width = (unit - socket_size)/2;
h_border_width = (h_unit - socket_size)/2;
v_border_width = (v_unit - socket_size)/2;
// Conversion factor from border width to mm (for use in layouts)
mm = 1/border_width;
h_mm = 1/h_border_width;
v_mm = 1/v_border_width;

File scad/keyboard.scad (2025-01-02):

include <parameters.scad>
include <param_processing.scad>

use <backplate.scad>
use <pcb.scad>
use <plate.scad>
use <case.scad>

echo(str("Total thickness is ", total_thickness, "mm."));

// Case
color("teal")
translate([
    0,
    0,
    -plate_thickness/2 + pcb_plate_spacing + pcb_thickness
        + pcb_backplate_spacing + backplate_thickness
]) {
    if (case_type == "sandwich" || case_type == "backplate_case") {
        plate(switch_layout_final, mcu_layout_final, trrs_layout_final, plate_layout_final, stab_layout_final, standoff_layout_final);
    } else if (case_type == "plate_case") {
        case(switch_layout_final, mcu_layout_final, trrs_layout_final, plate_layout_final, stab_layout_final, standoff_layout_final);
    } else {
        assert(false, "case_type parameter is invalid");
    }
}


// PCB
color("green")
translate([
    0,
    0,
    pcb_thickness/2 + pcb_backplate_spacing + backplate_thickness
]) {
    pcb(switch_layout_final, mcu_layout_final, trrs_layout_final, stab_layout_final, standoff_layout_final, via_layout_final);
}


// Backplate
color("maroon")
%translate([
    0,
    0,
    0
]) {
    if (case_type == "sandwich" || case_type == "plate_case") {
        backplate(switch_layout_final, mcu_layout_final, trrs_layout_final, plate_layout_final, stab_layout_final, standoff_layout_final);
    } else if (case_type == "backplate_case") {
        // Not implemented
    } else {
        assert(false, "case_type parameter is invalid");
    }
}

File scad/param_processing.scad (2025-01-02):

include <parameters.scad>
include <stabilizer_spacing.scad>
include <default_layout.scad>
include <layout.scad>

use <utils.scad>

// Post-processing of parameter and layout values

// Determine whether to invert the layout
switch_layout_final = invert_layout(set_defaults(base_switch_layout, false));
plate_layout_final = [
    for (group = base_plate_layout)
        invert_layout(set_defaults(group, ["switch"]))
];
mcu_layout_final = invert_layout(set_defaults(base_mcu_layout));
trrs_layout_final = invert_layout(set_defaults(base_trrs_layout));
stab_layout_final = invert_layout(set_defaults(base_stab_layout));
standoff_layout_final = invert_layout(set_defaults(base_standoff_layout, standoff_config_default));
via_layout_final = invert_layout(set_defaults(base_via_layout, via_shape));

assert(
    layout_type == "column" || layout_type == "row",
    "layout_type parameter is invalid"
);

assert(
    pcb_type == "printed" || pcb_type == "traditional",
    "pcb_type parameter is invalid"
);

assert(
    switch_orientation == "south" || switch_orientation == "north",
    "switch_orientation is invalid"
);

// Channels are modelled as a teardrop to print the overhang better.
// Since changing the row/column layout flips the switch print
// orientation, we also need to flip the teardrop.
upsidedown_switch = 
    layout_type == "column" ? false
    : layout_type == "row" ? true
    : undef;

// Moves the flat part to the top if layout is row-staggered so column wires
// can be routed. PCB should be printed upside down in this case.
border_z_offset =
    pcb_type == "traditional" ? 0
    : layout_type == "column" ? -1
    : layout_type == "row" ? 1
    : undef;

trrs_inset =
    pcb_type == "printed" ? 2
    : pcb_type == "traditional" ? 0
    : undef;

// Tweaks to make wire channels connect properly depending on the key alignment
row_cutout_length =
    layout_type == "column" ? 1000
    : layout_type == "row" ? 1000
    : undef;

col_cutout_length =
    layout_type == "column" ? 1000
    : layout_type == "row" ? 1000
    : undef;

switch_rotation =
    switch_orientation == "south" ? 0
    : switch_orientation == "north" ? 180
    : undef;

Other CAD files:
stl/default_layout/sandwich_case/backplate.stl
stl/individual_components/mx_socket_improved.stl
stl/individual_components/choc_switch.stl
scad/parameters.scad
example_layouts/crkbd/crkbd.scad
example_layouts/eggcat/eggcat.scad
example_layouts/jd40/jd40.scad
example_layouts/numpad/numpad.scad
plate.scad
scad/backplate.scad
scad/case.scad
scad/default_layout.scad
scad/diode_bending_template.scad
scad/grid_cutout.scad
scad/grid_patterns.scad
scad/mcu.scad
scad/pcb.scad
scad/plate.scad
scad/stabilizer.scad
scad/stabilizer_spacing.scad
scad/standoff.scad
scad/switch.scad
scad/trrs.scad
scad/utils.scad
scad/via.scad
stl/individual_components/mx_switch.stl
stl/individual_components/trrs.stl

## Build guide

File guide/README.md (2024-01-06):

# Guides
### [Design Guide](./design_guide.md)
Step-by-step guide on how to use the various layout options to design your PCB and case.

### [Build Guide](./build_guide.md)
Step-by-step guide on how to wire and assemble the keyboard.

### [Firmware Guide (Coming Soon)](./firmware_guide.md)
Step-by-step guide on how to create a VIA-enabled firmware and JSON file for your keyboard.

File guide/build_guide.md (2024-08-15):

# Build Guide

### Introduction
This guide covers how to print, wire, and assemble your keyboard once you've finalized your design. If you only need the PCB you can skip the parts that cover physical assembly.

### Bill of Materials
#### Consumables:
- 3D-printed PCB
- 3D-printed plate or integrated-plate case (optional)
- 3D-printed backplate (optional)
- 2-3 colors of stranded 22AWG silicone wire
- 1N4148 through-hole diodes (one per switch)
- Key switches (type depends on your configuration)
- Microcontroller board (optional)
- TRRS socket (optional)
- M2 screws (one per standoff, optional)
- Self-adhesive rubber feet (recommended)
- Electrical tape (recommended)

#### Tools:
- 3D-printed diode-bending guide
- Utility knife (choose one with a narrow blade, like an Olfa or Xacto)
- Wire strippers
- Screwdriver (profile depends on your screws)
- 1mm drill bit and pin vise (optional)
- 1/16" drill bit (optional)
- Electric drill (optional)
- Sewing needle, sewing pin or drawing pin
- Flush cutters (recommended)
- Needlenose pliers (recommended)
- Tweezers (2A-SA profile recommended)
- Switch puller (recommended)

### Printing Tips
Plates, cases, and backplates are pretty straightforward to print, as long as your printer can produce reasonably accurate holes (&pm;0.2mm). The most important thing to remember on the plate is to try to avoid squishing the first layer too much (i.e. elephant's foot), as that can cause your holes to be undersized and require you to spend a bunch of time trimming away the excess material. If you're using a 1.5mm plate, you may want to adjust your first layer height to make sure you can hit that exactly (e.g. for 0.2mm layers, set the first layer height to 0.3mm). This isn't strictly necessary, as 1.6mm plates work almost as well (FR4 plates are 1.6mm). I usually use 2 perimeters on a 0.4mm nozzle and enough top/bottom layers to make the whole plate solid infill. An infill percentage of 15% is sufficient. No supports should be needed for anything.

When printing the PCB, you may want to slow down your perimeter speed because there are a lot of small features that can cause fit issues if they're a little out of spec. It's better to spend a little more time printing and save yourself time cleaning up a ton of tiny holes and channels that didn't quite come out right. You should also make sure your flow and retraction are calibrated properly so you don't get underextrusion on small features like standoffs and the tops of wire channels. If you're printing a staggered-row layout, you should print the PCB top-side-down so that you don't end up with a bunch of unsupported bridges and overhangs.

In general, I recommend printing out standalone switch, MCU, and TRRS sockets to test fit before you print the full PCB. You can use these test fits to tweak the values in `parameters.scad` to best suit your particular printing setup, as well as calibrate your printer for the holes etc.

### Print Cleanup
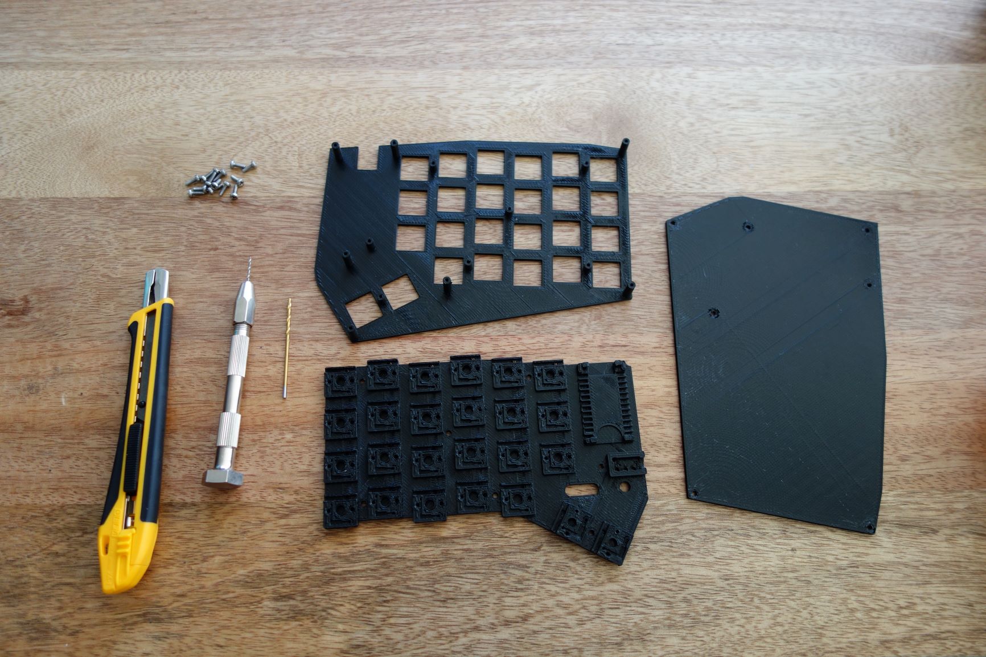
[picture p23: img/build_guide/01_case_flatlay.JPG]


Unless your printer is super dialed-in, you'll probably need to do some amount of cleanup on your parts after you've printed them.
The tools you might need for this, depending on the issues you have, are a utility knife, a 1mm drill bit in a pin vise (which is a handle you use to hold tiny drill bits), and a 1/16" drill bit in an electric drill.

As mentioned previously, elephant's foot can cause issues with the switch cutouts in the plate. If you notice this, use your utility knife to trim off the excess. If you find yourself needing to take off a lot of material, it may be faster to tweak your print settings and print it again.

If any standoffs have their internal holes plugged up, the 1/16" drill bit is the exact size needed to create a good pilot hole that the screws can cut threads into.

On the PCB, the two most common issues involve the small holes that hold the switch pins. On the top side, the holes that hold the small plastic pins can easily get clogged up or be a little misshapen, causing the switch to not fit nicely, as in the image below). You can clear these holes by gently drilling them out with the 1/16" bit for a near-perfect fit.
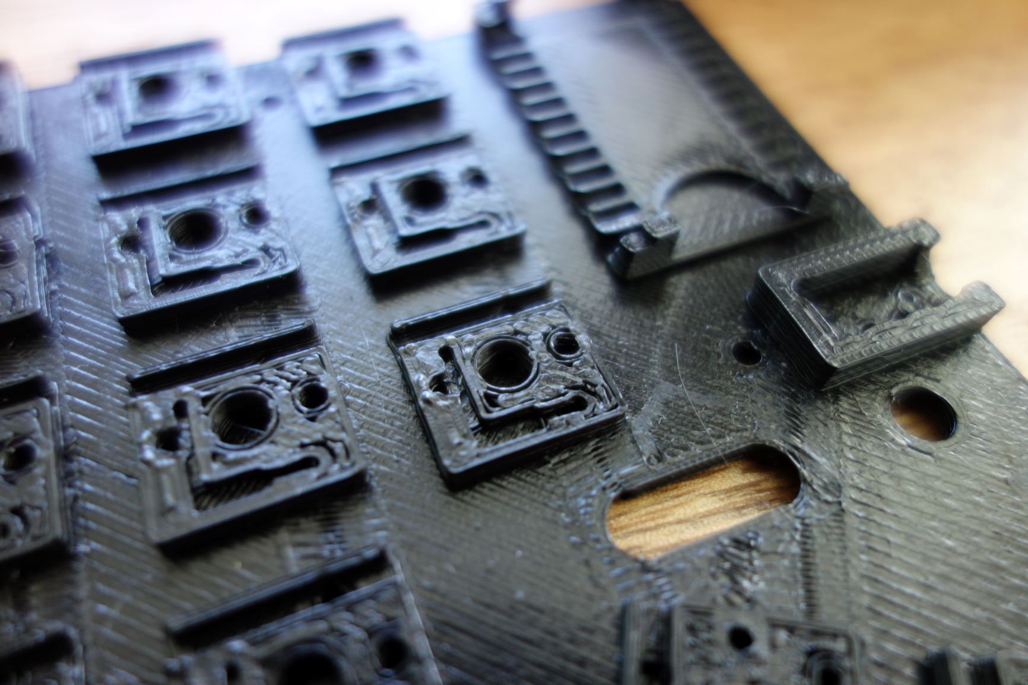
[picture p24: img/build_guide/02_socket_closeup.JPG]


On the bottom of the PCB, the small channels that the diode legs go through can also be easily clogged up.
If they aren't too clogged, especially if it's just a bit of elephant's foot, the sewing needle or pin can often get through these fine.
Otherwise, you can drill these out from the top with the 1mm bit. Be careful not to apply too much downward force, as you can easily snap the bit.
<p align="center">
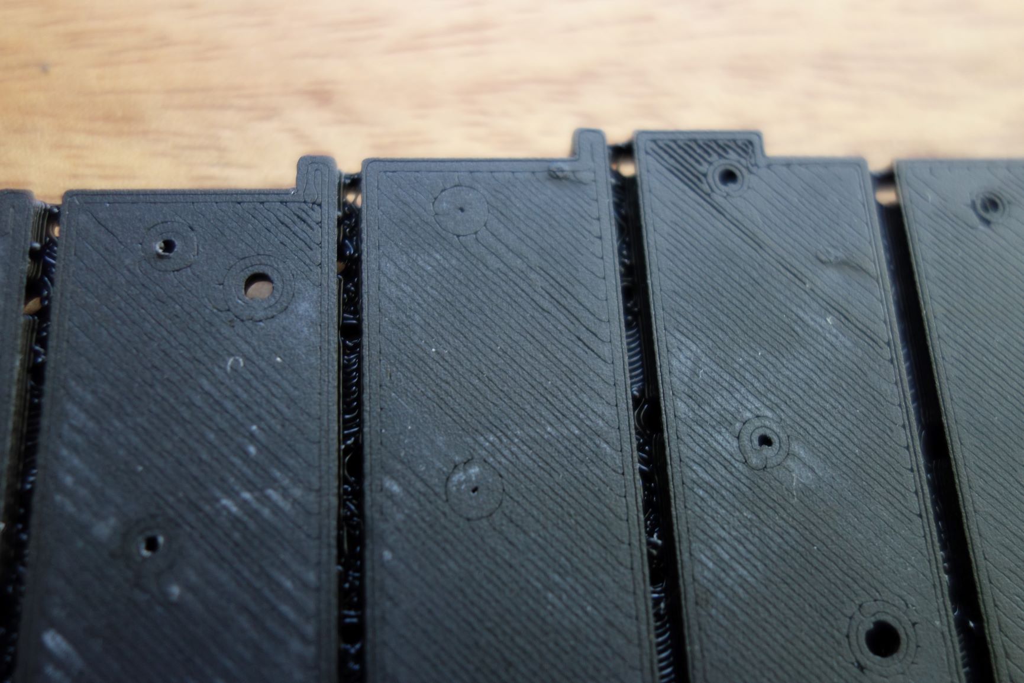
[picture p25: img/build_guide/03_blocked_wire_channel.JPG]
    
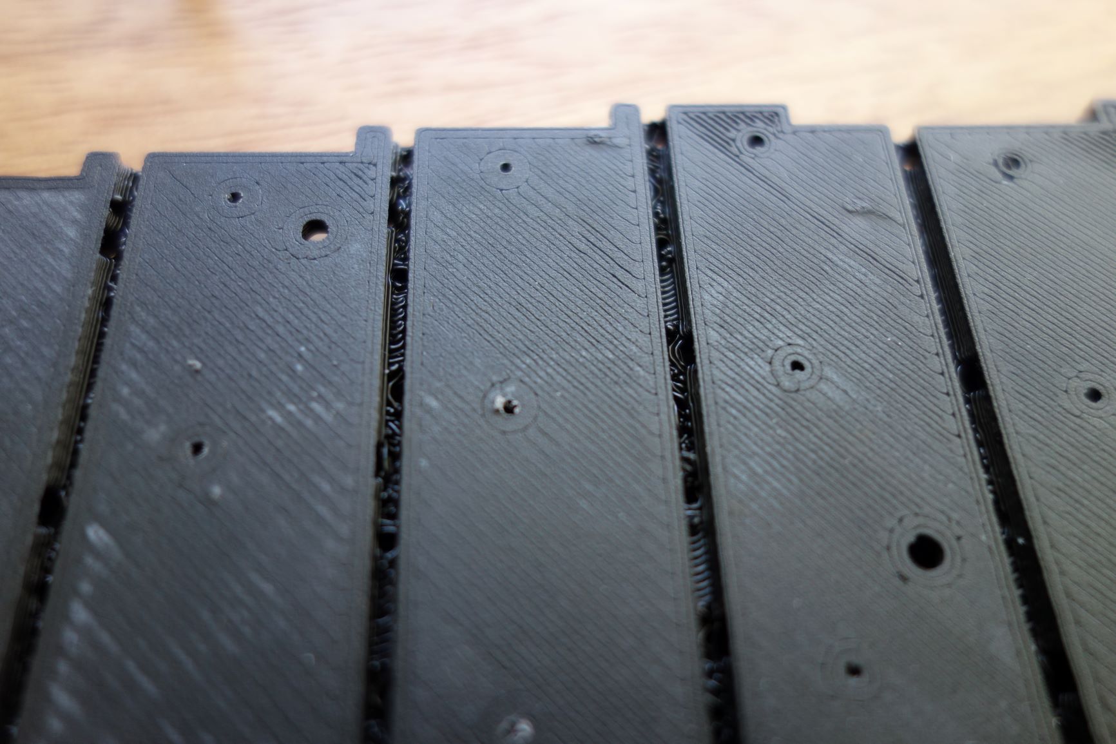
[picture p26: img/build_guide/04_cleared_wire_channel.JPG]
    
</p>

The wire channels on the PCB can also be affected by print artifacts. Elephant's foot can cause the openings to be too narrow for the wire to be easily pressed into place. If this happens, use the utility knife to carefully trim away the excess material around the edges.

If the fit on the MCU socket is too tight for the MCU to snap in place, you may need to slightly trim or sand down the bottom tabs, or reprint the PCB with a slightly larger `mcu_length` value.

The TRRS socket has 4 small holes that go through the PCB and must be large enough to thread your wire through. The fit should be snug, but not overly tight. The 1/16" drill bit also seems to be a good size to clear out any printing artifacts. If the socket doesn't fit, you can trim the edges a bit, but you may be best off changing the model size slightly and reprinting.

Before you proceed you should do a test fit of each socket, as it's easier to correct issues before the PCB is wired up.
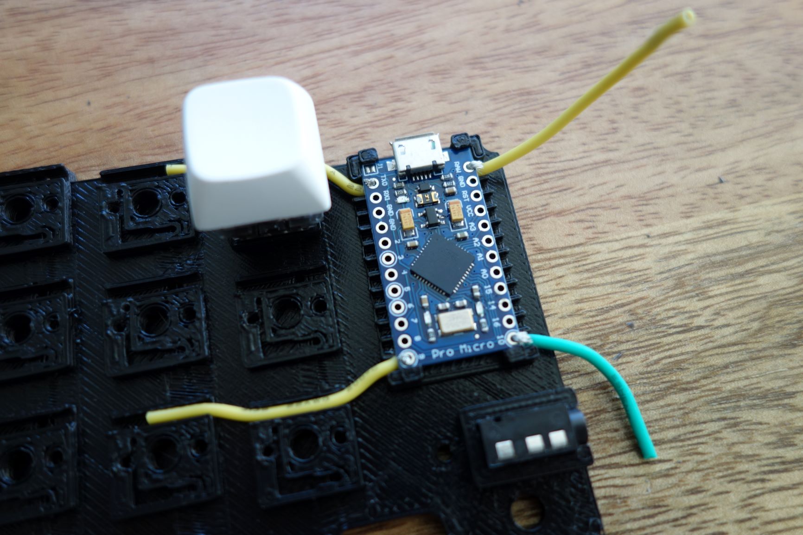
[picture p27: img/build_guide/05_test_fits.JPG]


### Wiring
When wiring your PCB, it helps to use different colors for your row, column, and TRRS wires (if applicable). Use the PCB to measure out and cut each row and column wire, taking into account routing to the corresponding MCU pin and adding a bit of excess length just in case.
<p align="center">
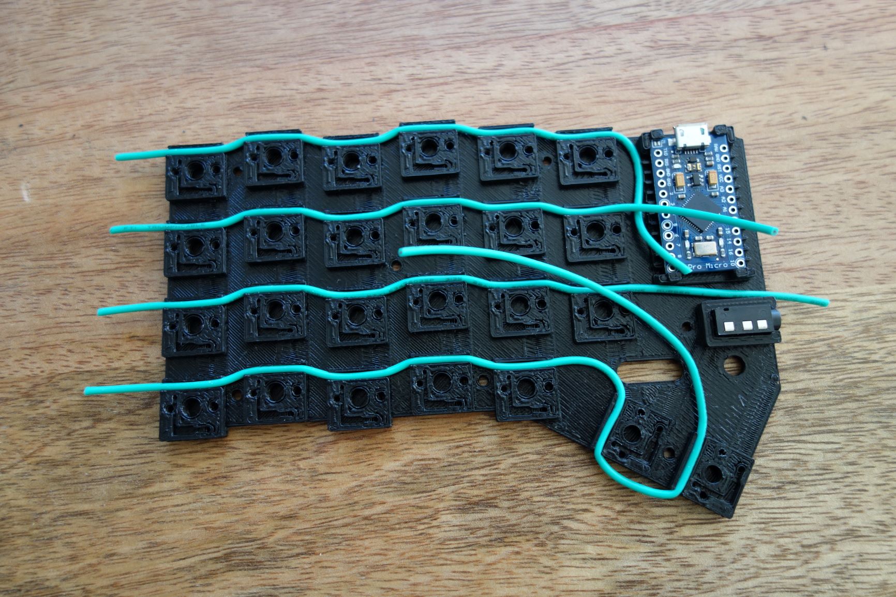
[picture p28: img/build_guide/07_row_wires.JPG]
    
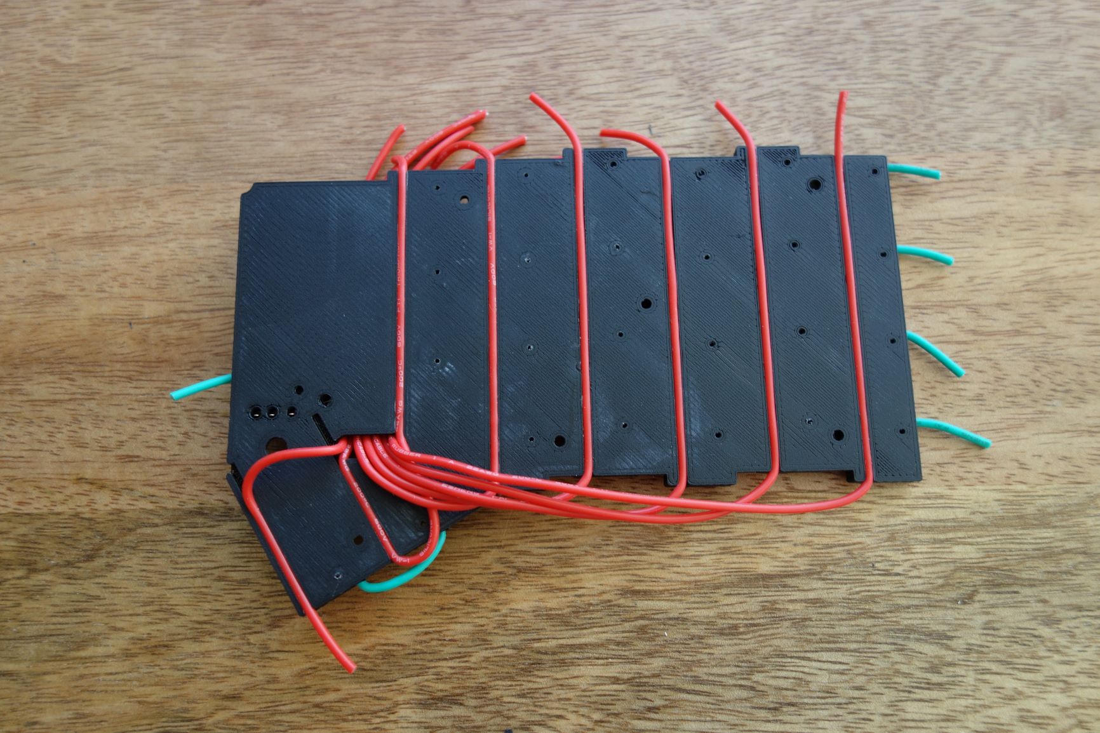
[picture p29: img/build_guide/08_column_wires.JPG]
    
</p>

Next you should measure out your wires for the TRRS socket. For these, you should start by threading one end up through the PCB so it sticks out past the socket. Lay it along the route you want it to take to the PCB and cut close to the final length. Once you have all 4 wires cut, insert each leg of the TRRS socket into the end of its corresponding wire. I recommend connecting the VCC wire to the tip contact and Ground to the sleeve contact, so that they don't short when the cable is plugged/unplugged. Pull gently downward on all the wires until the socket is sitting just above the PCB, and then press the socket into place. The wires with the socket legs should be slightly oversized for the holes in the PCB, creating a friction fit that holds the wires securely. Route the wires to the MCU socket.
<p align="center">
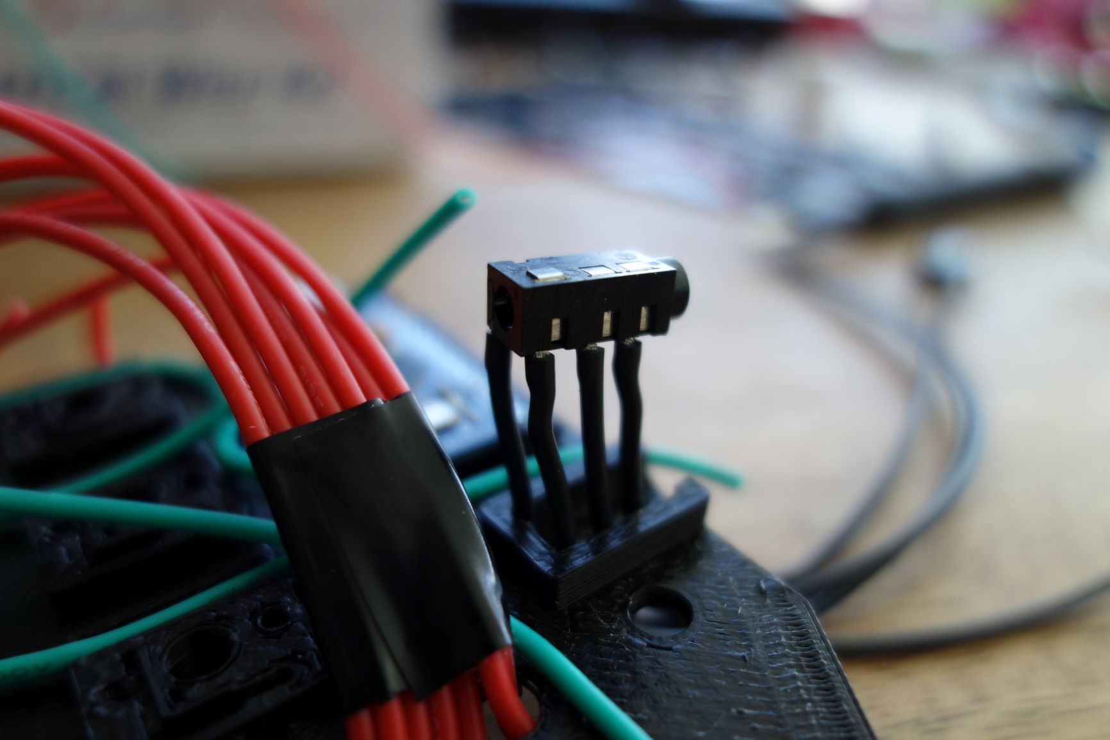
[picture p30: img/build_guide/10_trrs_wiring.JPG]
    
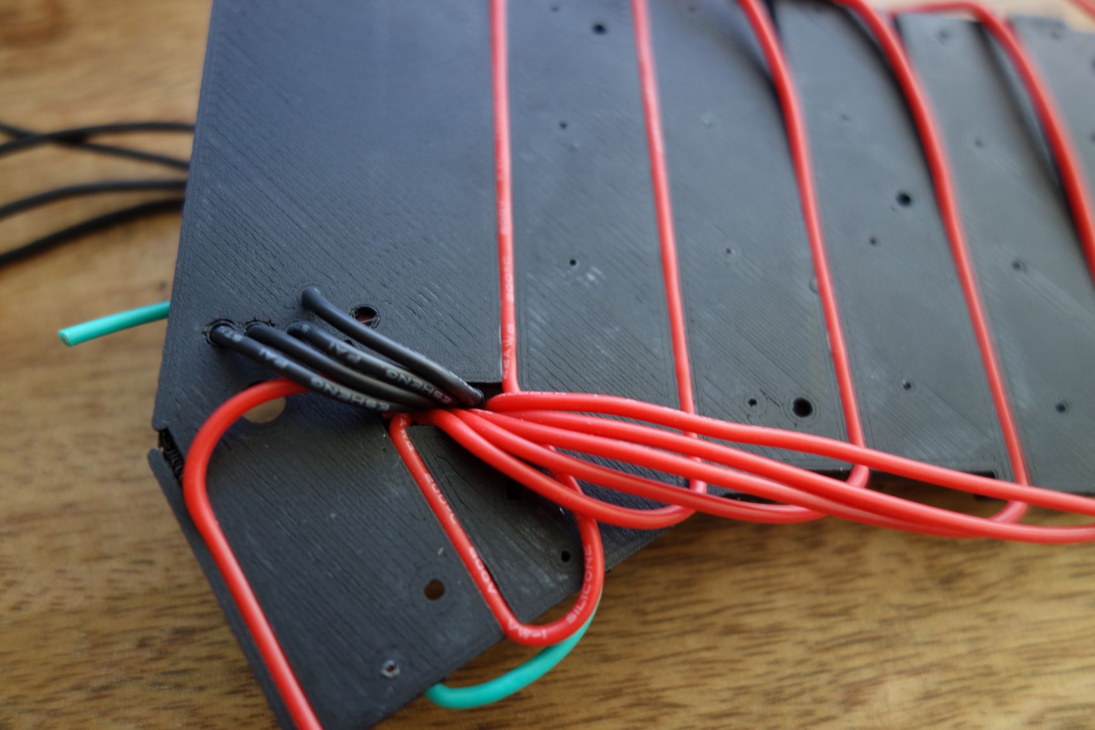
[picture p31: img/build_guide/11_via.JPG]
    
</p>

After you have all your wires cut you should attach them to the MCU. For each wire, strip ~5mm of insulation off the end and twist so that it stays together. If you're just prototyping, you can connect them to the MCU by simply threading the stripped end through the plated through hole and folding it over. When the MCU is snapped into the socket all the wires will be held in place reasonably securely. You're free to solder these joints if you need a more robust connection, but it's not strictly necessary. The row/column wires can be removed from their channels for this step, but the TRRS wires should be routed in their final configurations. I usually start with the TRRS wires since they are the most constrained. After you have all the wires connected you can snap the MCU in place to lock them in. It's easiest to start with the connector side in first so you can press down on the PCB without damaging the connector. Make sure all the wires are roughly perpendicular to the sides of the MCU so that they sit properly in their channels. Use the tweezers to make sure that adjacent wires aren't shorting with each other.
<p align="center">
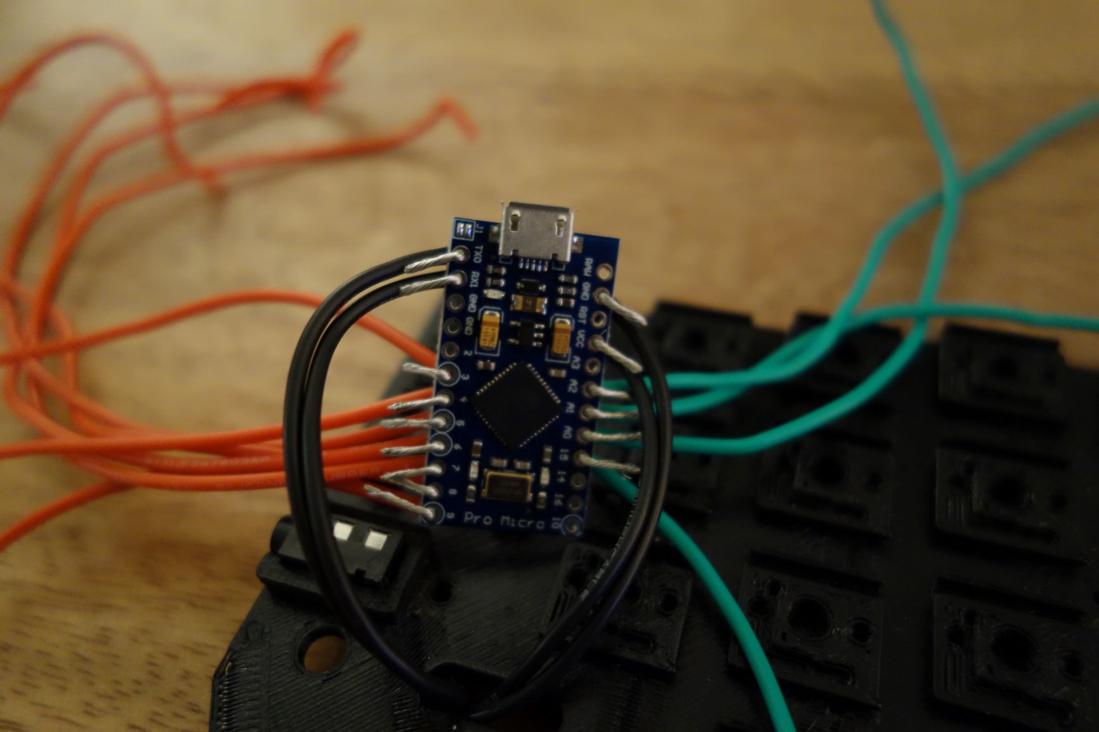
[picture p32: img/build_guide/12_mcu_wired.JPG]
    
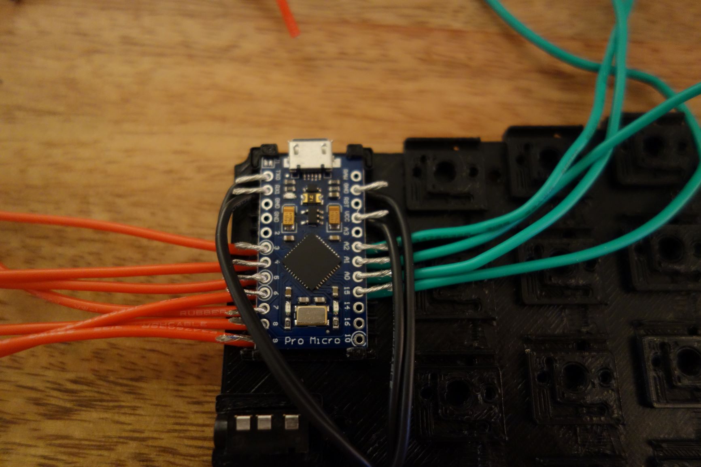
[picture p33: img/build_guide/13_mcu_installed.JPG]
    
</p>

### Diodes
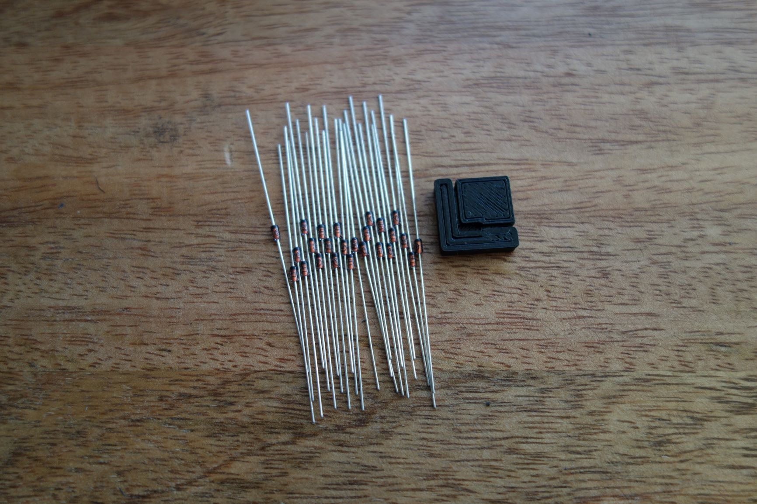
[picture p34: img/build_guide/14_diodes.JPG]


The diodes get their own section because they are the most tedious part of the build. I would highly recommend 3D-printing the diode bending guide, which makes the pre-bending step much faster and much more repeatable. The first step for each diode is to make a 90-degree bend in the diode's anode leg (the leg further from the black stripe) as close to the housing as possible. This will allow you to place the diode in the bending jig, and from there you just bend both legs down at a 90-degree angle. Repeat this step for each diode.
<p align="center">
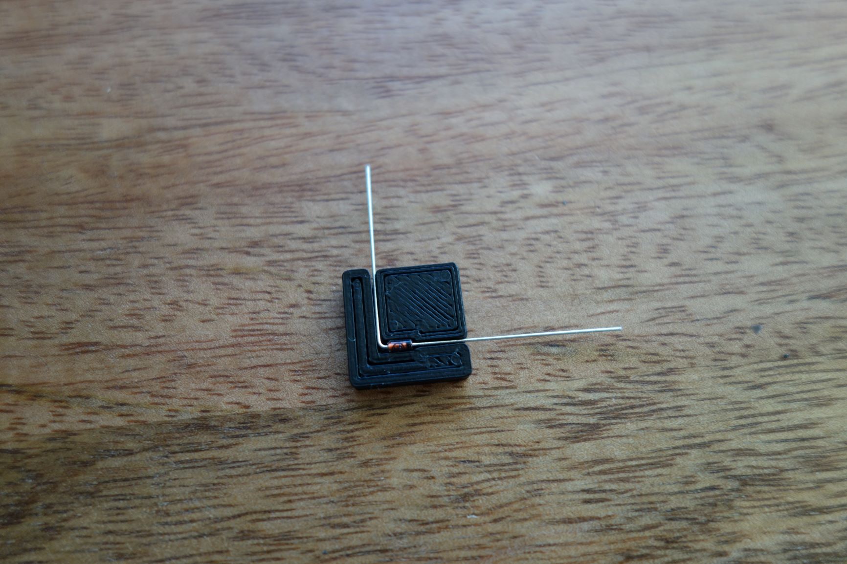
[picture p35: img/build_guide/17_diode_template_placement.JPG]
    
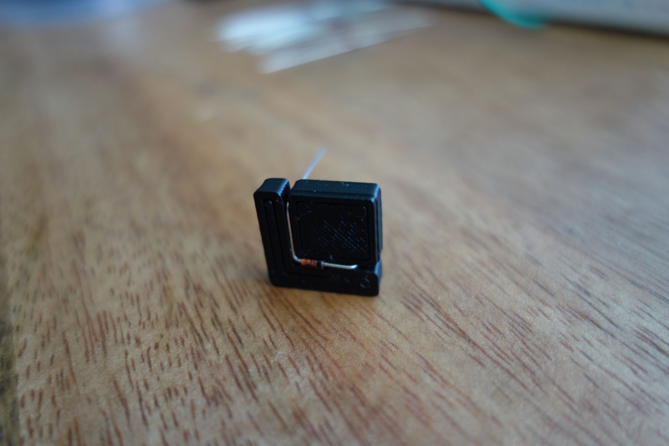
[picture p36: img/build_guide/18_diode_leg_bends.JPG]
    
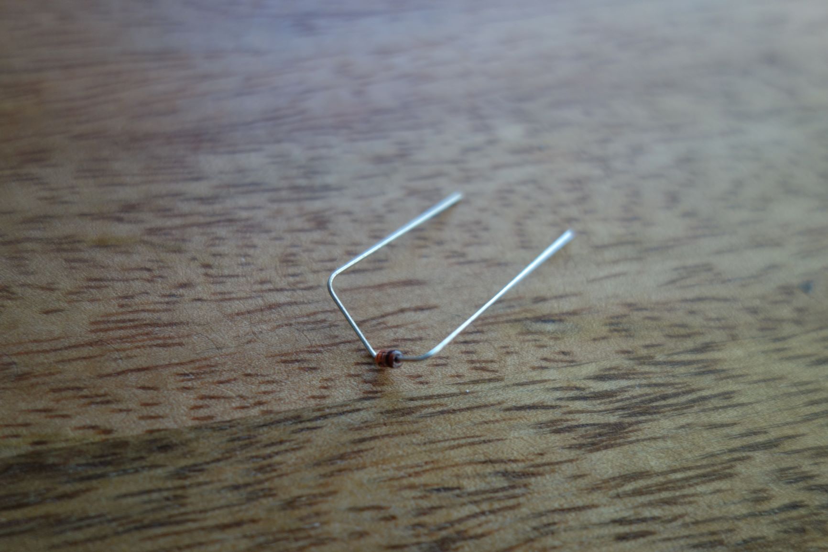
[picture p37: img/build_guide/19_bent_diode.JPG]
    
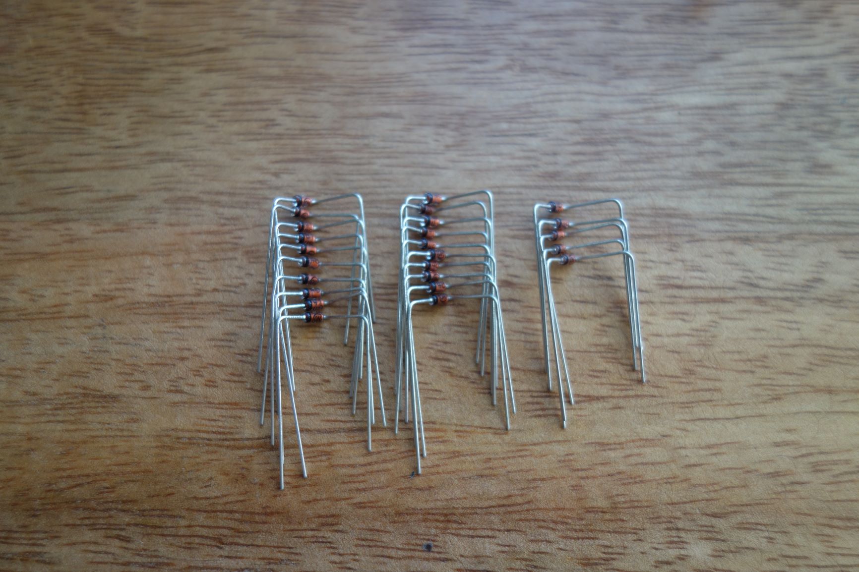
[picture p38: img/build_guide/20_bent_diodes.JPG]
    
</p>

The anode leg of each diode goes through the same hole in the socket as the bottom switch pin, while the cathode leg goes through the column wire on the back of the PCB. In order to get the diode leg through the wire, you must first pierce a hole through the wire using the sewing needle. Hold the wire down to the PCB on either side of the hole and poke the needle through the hole and through the wire. It may help to twist a bit as you push to ease it through. Make sure the needle went through the actual strands of wire and not just through the side of the insulation. Pull the needle all the way through and then carefully push the diode leg through the hole you just created. If you encounter too much resistance, just run the needle through again to widen the hole. Once the diode is through, bend the bottom leg to the right to lock the wire in place and ~bend the top leg upwards to lock the diode in place~ - Actually, don't do this. Use tape to hold the diode if you need to, but the first bend might be sufficent. Make sure the diode legs aren't touching each other, or you might get issues with ghosting using NKRO.
The pictures below have the wires touching, which shorts the diode and makes it pointless.
Trim the legs, leaving about 5mm on each.
<p align="center">
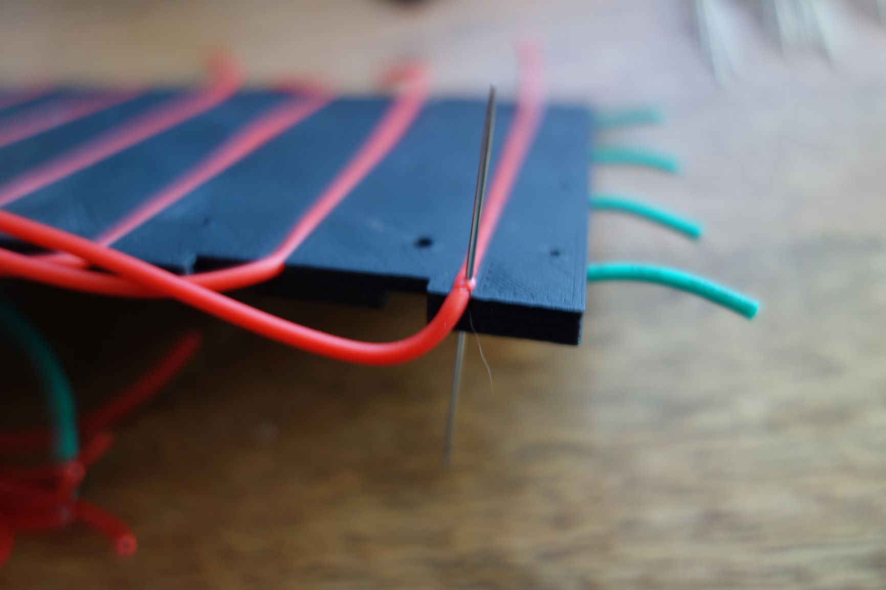
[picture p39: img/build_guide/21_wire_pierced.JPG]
    
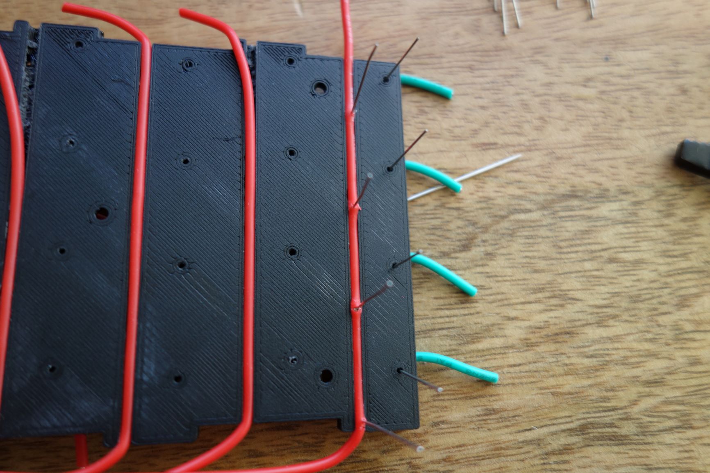
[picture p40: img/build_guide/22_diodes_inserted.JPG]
    
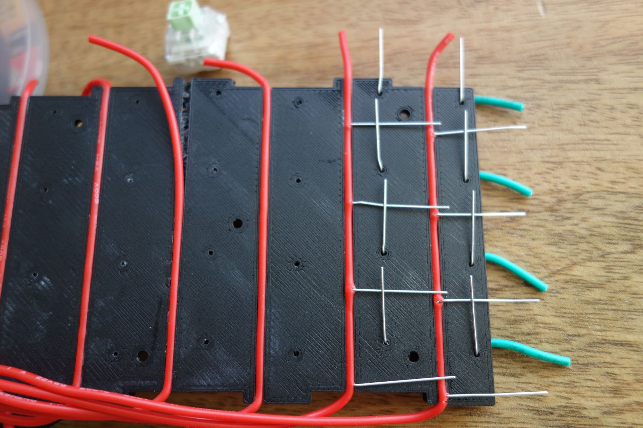
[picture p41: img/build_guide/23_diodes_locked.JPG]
    
</p>

On each switch socket, use the utility knife to cut a slit in the row wire insulation where the top switch pin will be inserted. This isn't strictly necessary, but helps improve ease of installation and reduce the incidence of bent switch pins.
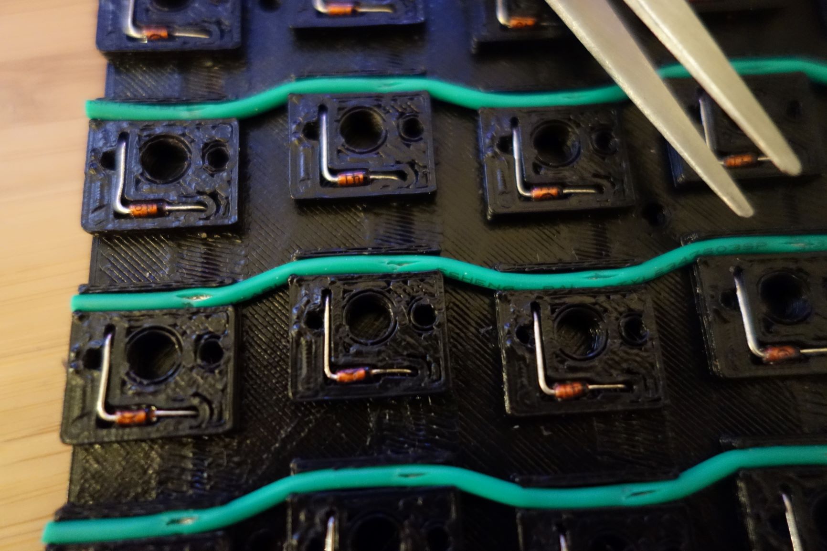
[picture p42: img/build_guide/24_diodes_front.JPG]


Note that either diode orientation will work, as long as you're consistent. The orientation described here corresponds to a `ROW2COL` diode direction in QMK.
(Note that the QMK default is COL2ROW, so be sure to change this in firmware).

### Testing
Before you assemble, it's a good idea to do a test fit of all the switches you want to use and test the switch matrix, as it's much easier to fix electrical problems before you have everything cased up. This will also slightly bend the diode and switch legs, making them easier to insert later. I use VIA to test the matrix, though if your firmware isn't VIA-enabled you can still just test every key and make sure the keyboard outputs the right values. See the [Firmware Guide](./firmware_guide.md) for instructions on how to create a VIA-enabled firmware and corresponding JSON file.

### Assembly (optional)
At this point the electronics are complete, so we can assemble the keyboard. If you're only using the PCB from this repo, you can assemble it according to whatever case you're using. For each standoff in your assembly, it's a good idea to precut the threads for easier assembly later. Place a screw in the pilot hole and press down firmly with your screwdriver. Screw it in slowly while continuing to apply downward pressure until the screw is as deep as you need it to go in your final assembly. Make sure that the end of the screw doesn't go past the bottom of the standoff, as this can cause the standoff to break off.
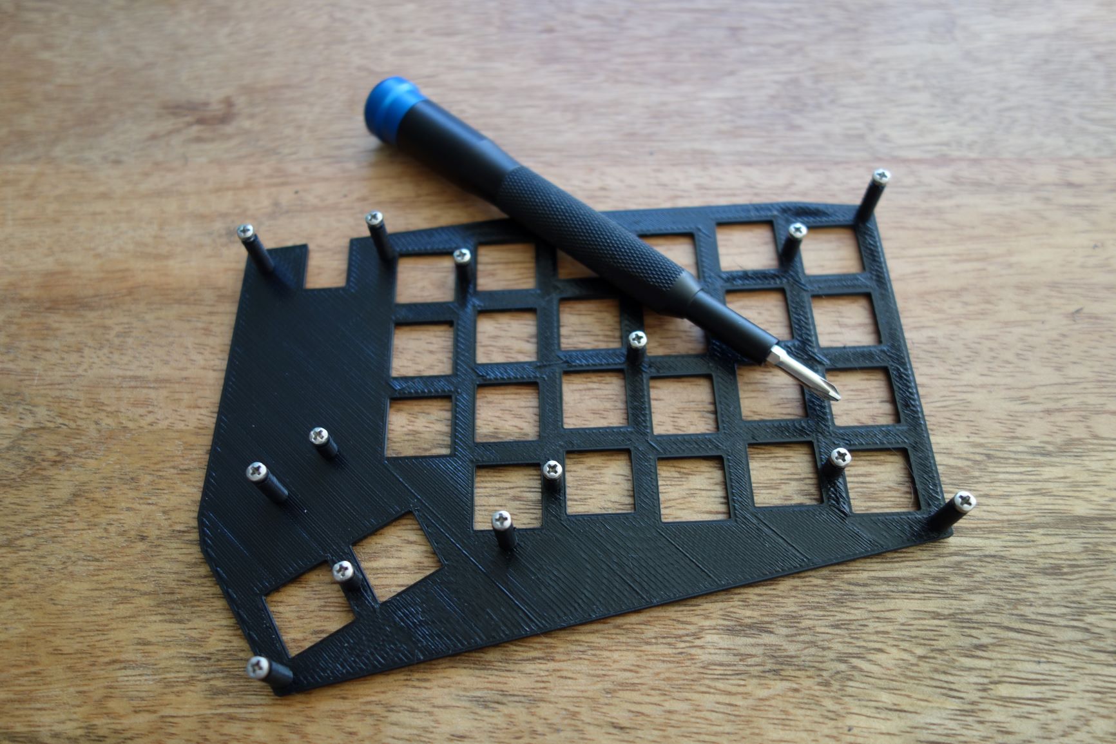
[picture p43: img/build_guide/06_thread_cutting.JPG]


Remove the screws from the standoffs and assemble your keyboard based on your standoff layout. In this example the plate has all the standoffs, connecting to both the PCB and the backplate.
<p align="center">
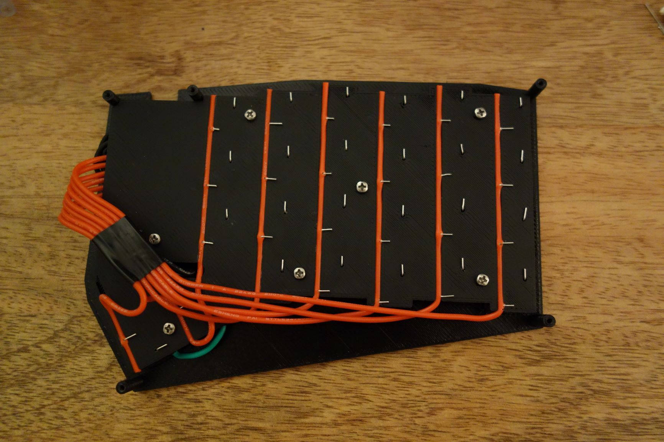
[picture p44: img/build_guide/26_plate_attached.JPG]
    
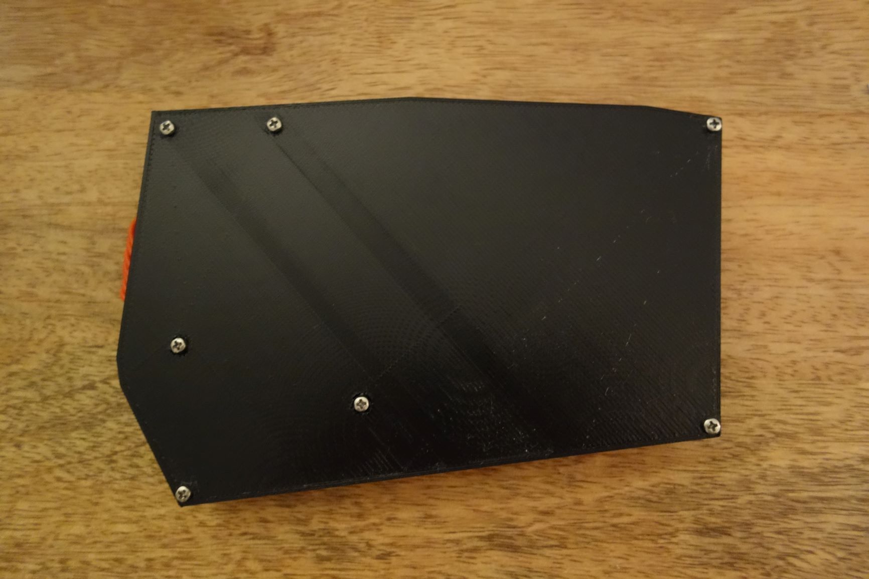
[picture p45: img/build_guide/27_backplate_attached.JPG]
    
</p>

Finish off the assembly with some rubber feet on the bottom and install your switches.
<p align="center">
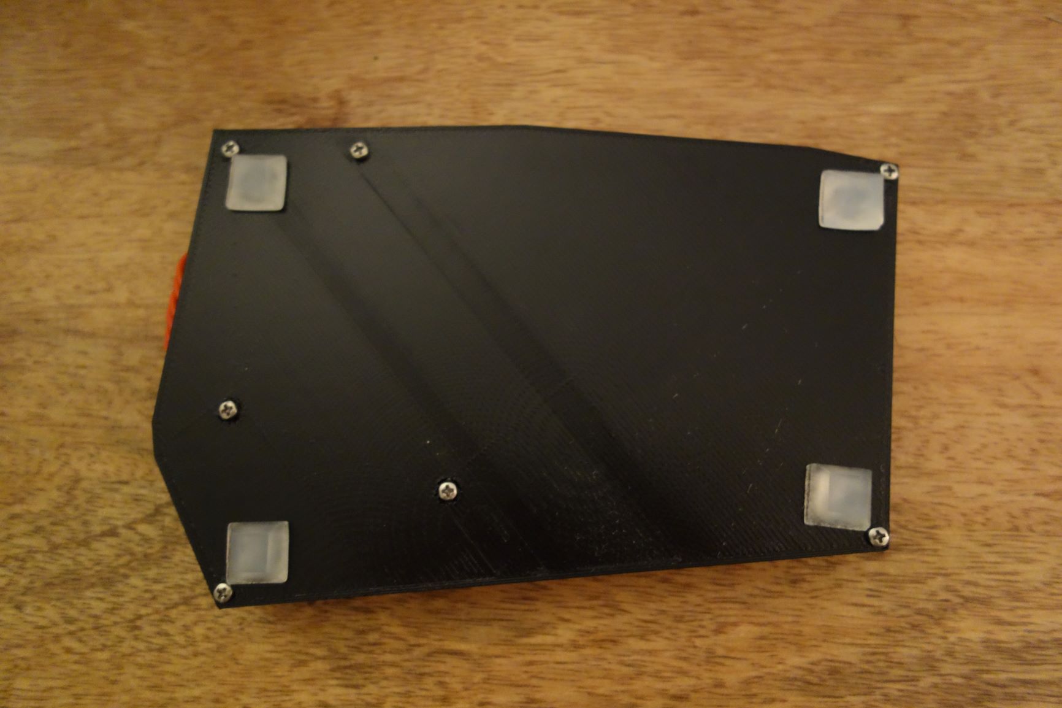
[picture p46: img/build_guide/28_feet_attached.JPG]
    
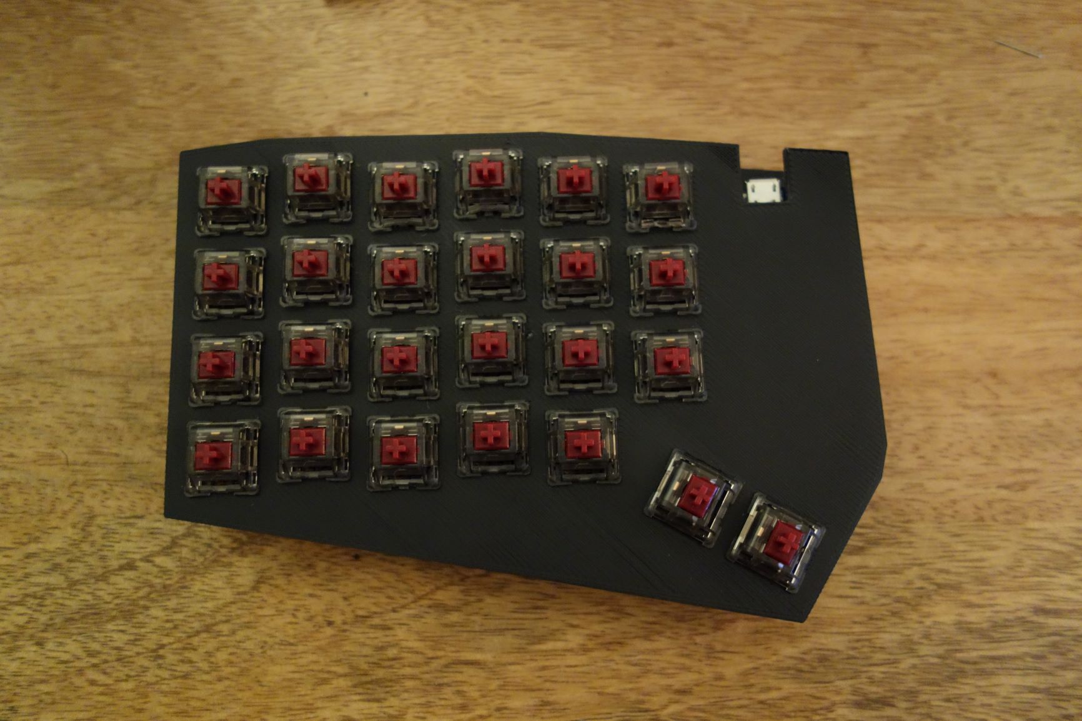
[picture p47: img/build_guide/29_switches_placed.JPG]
    
</p>

You're done! Post a picture on Reddit or something. I'd love to see what you came up with.

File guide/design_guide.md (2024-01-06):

# Design Guide

### Introduction
This guide covers how to transform a KLE layout into a `layout.scad` file that you can use to generate STLs for a PCB, plate, and/or case.

### Keyboard Layout Editor
While it's possible to manually enter all of your key positions into `base_switch_layout`, I highly recommend using [keyboard-layout-editor.com](http://www.keyboard-layout-editor.com/) to create your initial layout. It provides a graphical interface and intuitive controls that allow you to easily position, resize, rotate, and label keys to form a keyboard layout. Most importantly for our purposes, these layouts can be exported in a JSON format that can be used for other applications that need to represent a keyboard layout, like this tool. Despite some spotty maintenance and a somewhat restrictive license, the JSON format has become something of an industry standard for representing keyboard layouts. Most common keyboards already have KLE layouts available, which you can find with a little bit of searching. Any layout JSON can be downloaded by clicking the green "Download" button at the top right, and selecting "Download JSON" from the dropdown.

For this tutorial, we will be using the default layout, which I've tentatively named the Siamese Kitten. A screenshot of its KLE representation (with matrix locations on the keys) is shown below. You can view the original layout [here](http://www.keyboard-layout-editor.com/#/gists/9c44a869ba4c04c40b0c1d6b4f704bc2).
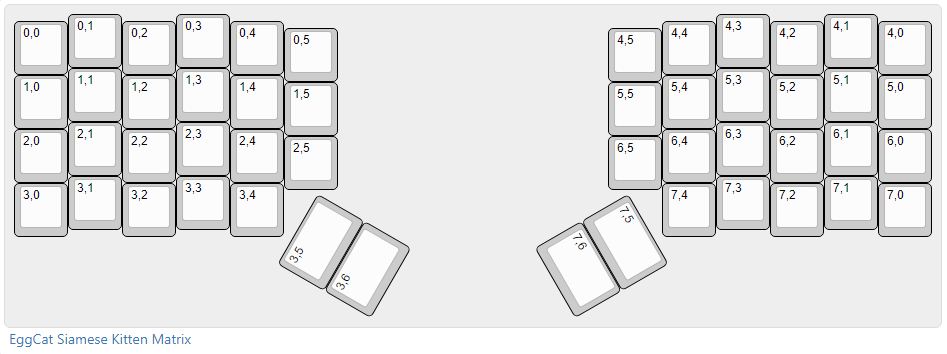
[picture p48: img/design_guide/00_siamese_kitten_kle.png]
Siamese Kitten KLE


When creating your own layout for use with this tool, the labels on each key are ignored, so you can use any layout that has the proper key positions and shapes. This tool can also only handle keys that are exactly 1 unit tall, because of how it calculates the locations of keycap stems. If you want a vertical 2-unit key, you can get around that by creating a horizontal 2-unit key and rotating it 90 degrees. For keys like ISO Enter, replace them with a key that has the same stem layout. If you're working with a split layout, you should export the two sides separately. If the two sides are symmetrical, you only need to export the left side, since the whole layout can be flipped in SCAD.

### Conversion Script
The bridge between KLE and OpenSCAD is the conversion script located in the [`script/`](../script/) directory. This will take a KLE JSON file and plug the key location data into a template for `layout.scad`, which is placed in the `scad/` directory. Here's the basic usage:
```
npm start -- <layout json file> <optional output filename>
```
See the `script/` README for more details on installation and usage.

### `layout.scad` & `parameters.scad`
After running the conversion script, you'll have a `layout.scad` with `base_switch_layout` populated, but everything else empty, which will result in a PCB that looks something like this:
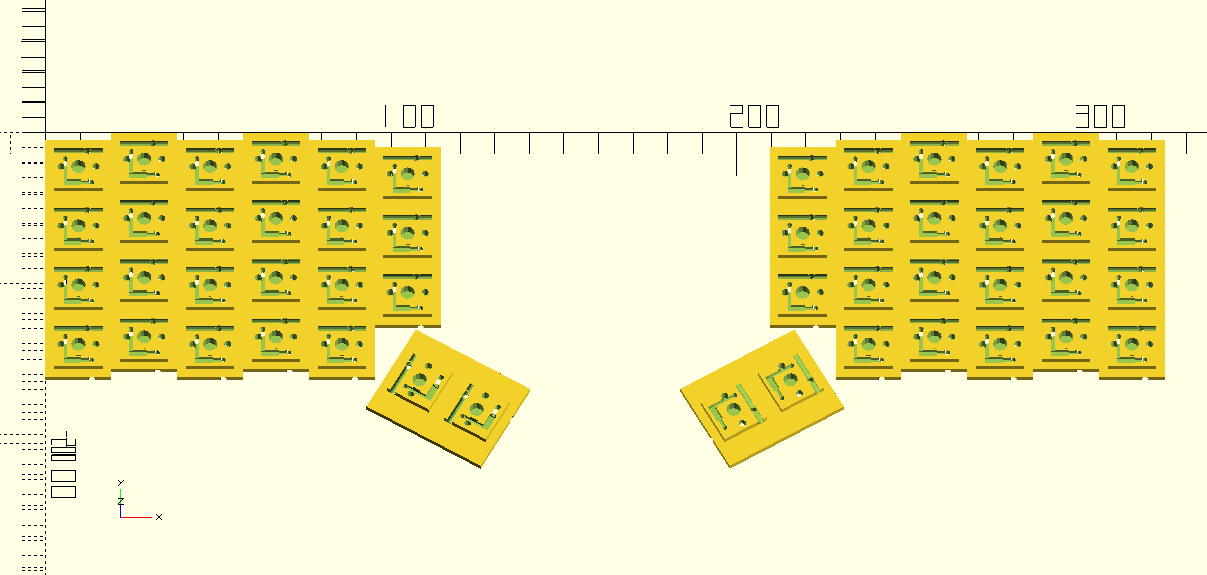
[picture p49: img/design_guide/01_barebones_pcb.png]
Barebones PCB


As you can see, I didn't take my own advice, and exported both hands in the same file. This can be fixed by deleting all the elements in `base_switch_layout` where `x_location > 10`. If your layout is column-staggered, you may also notice that the keys in `base_switch_layout` are jumbled up, since KLE exports key locations in row-major order. You may want to rearrange the keys by columns so it's easier to read.

In order to customize the keys further, you'll want to get familiar with the data format that the SCAD code uses to represent layouts. Each layout variable is a vector, where each element is in this format:
```
[
    [                                       // Location Data
        [x_location, y_location],
        key_size,
        [rotation, rotation_x, rotation_y],
    ],
    [                                       // Borders
        top_border,
        bottom_border,
        left_border,
        right_border
    ],
    extra_data                              // Extra data (depending on component type)
]
```
There are 3 components to this vector: location data, borders, and extra data. Let's dive a little deeper into each of them.

#### Location Data
This is the data that we get from the KLE JSON. For each key, `[x_location, y_location]` defines the position of the top left corner of the key, represented in key units. Note that the y-axis points downwards, with the origin at the top left corner. `key_size` defines the horizontal width of the key, also in key units. `[rotation, rotation_x, rotation_y]` defines a point around which to rotate the key, and the angle at which to rotate it counterclockwise. Note that the rotation direction is the opposite of what KLE uses, but the conversion script should handle this for you.

Both key size and the rotation data are optional, though if you include rotation data you must also include the key size.

#### Switch Options
Next we'll take a quick detour to discuss switch options. These are located in `parameters.scad`, and the main choice you have to make is between MX and Kailh Choc switches. This affects the socket generated, since the pin arrangement is different, and it also determines the plate thickness and PCB-plate spacing (used for the standoffs).

#### Borders
The border vector defines the width of the recessed border that runs around each key socket, as a multiple of `border_width`. `border_width` is defined as the distance between the edge of the socket and the edge of a 1-unit footprint, and was defined this way so that a border of `[0,0,0,0]` generates a socket with no border, while `[1,1,1,1]` generates a socket with a 1-unit footprint. If you wish to define a border in millimeters, simply multiply by `mm`, which is a helper value defined under the hood as `1/border_width`. The conversion script automatically generates borders that match the footprint of the key, which for a normal keyboard layout will generate a perfectly connected PCB. The border vector is optional, with a default value of `[1,1,1,1]`, though it must be defined if `extra_data` is used.

In the PCB above, you can see that all the adjacent sockets are connected, but since the thumb clusters don't sit on the grid they're kind of floating out there. If you're just looking for something quick, this can still be wired up, but it's nice to have the PCB be one piece. To do this, we can extend the top border of the top thumb cluster key by 25mm, and the bottom of the 6th column by 15mm. You can also reduce the footprint of the PCB by zeroing borders along the outside edge, which can be helpful when fitting the PCB into a case. Here's what the PCB looks like after the border changes:
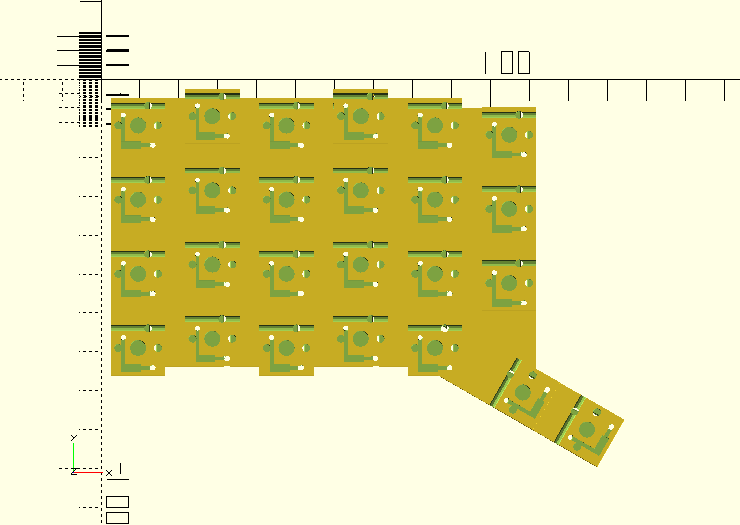
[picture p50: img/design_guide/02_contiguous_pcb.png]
Contiguous PCB


If you're creating a row-staggered layout, you'll want to set `layout_type = "row"`, which will cause the borders to be shifted to the top side of the PCB, making column wire routing cleaner. This also means that your PCB should be printed upside down to reduce unnecessary overhangs and bridges.

#### Extra Data
This is a catch-all field for extra data that is passed into the component module, and what it is depends on the component type. For `base_switch_layout`, this is a boolean value that defines whether or not the wire channel on the bottom of the PCB is rotated 90 degrees, which can be useful for wire routing on thumb cluster keys (or any other rotated keys). On the default layout I like to rotate the columns on both the thumb keys. We'll cover other uses of `extra_data` as they come up.

#### Other PCB Components (MCU, TRRS, stabilizers)
In addition to key positions, you have the option to add an MCU (like a Pro Micro) and/or TRRS socket to your keyboard, via the `base_mcu_layout` and `base_trrs_layout` variables. These use the same layout format described above, and don't use `extra_data`.

The standard values for the MCU fit a Pro Micro or equivalent controller, though you may want to tweak values a bit to account for printing tolerances. To make it easy to position the MCU in relation to your switches, the MCU socket footprint is sized in increments of 0.5 key units. You can change this behavior via the `mcu_unit_resolution` variable in `parameters.scad`. You can check the size of the footprint in `mcu.scad`, which will echo the size to the console when run. For the Pro Micro, the footprint is 2 units long by 1.5 units wide. `key_size` should be set to `mcu_h_unit_size` for positioning to work. Make sure the connector at the top of the MCU is accessible when you position this.

The TRRS socket is designed to accommodate a PJ-320A TRRS jack, which seems to be the de-facto standard for split boards, and is readily available. The socket footprint for this is 1 key unit, with the jack centered and pointing upwards. Position this as you would with a key, rotating from the center of the key if you want it to be in a non-vertical orientation.

Once again, you should modify the borders to get these components to connect to the rest of the PCB. For both of these components, borders are sized in mm. You can use `unit` and `border_width` to help you align these to exact measurements if desired, though you usually don't need to be so precise. For the TRRS especially, remember that the borders are generated relative to the unrotated position.

Here's what the PCB looks like after adding the MCU and TRRS socket:
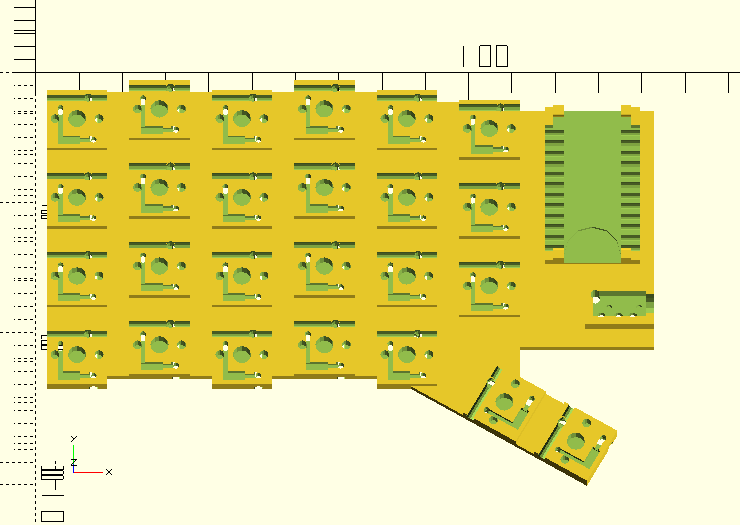
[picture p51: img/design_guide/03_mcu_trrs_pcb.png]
MCU/TRRS PCB


This is also the stage at which you can add stabilizers, if applicable. Once again, there's a layout vector, and `extra_data` is defined as `[key_size, left_offset, right_offset, switch_offset=0]`. Luckily, you shouldn't need to actually set those values yourself. Presets for all the common key sizes are located in `stabilizer_spacing.scad`, along with an explanation of how to measure all the relevant values. See the `numpad.scad` example layout for a sample usage of this. You shouldn't need to add additional borders here, since it will sit inside the borders automatically generated for the wider key.

#### PCB Shaping
After you have all of your components placed, there are some more refinements that can be made to the shape of the PCB. In particular, you may want to close up the gap between the thumb keys and the TRRS socket. To do that, you should extend the right border of the thumb cluster and the right border of the TRRS socket (which is rotated to be the bottom border) until they meet. With some math or trial-and-error you can get them to meet approximately at a point. Ideally, you should get them within 0.01mm, which will help when shaping the plate later. I'm working on a more elegant way to do this, but this works well enough for now.

Thinking ahead a bit, you probably want your column and TRRS wires to be easily routable from the bottom of the PCB to the top without going all the way around, You can do this using a via, which is just a hole in the PCB (the bootleg version of a real PCB via). Vias are laid out like any other component, with `extra_data = [via_width, via_length]`. For more details, check the `scad/` README.  

If all you needed is a PCB, you're done:
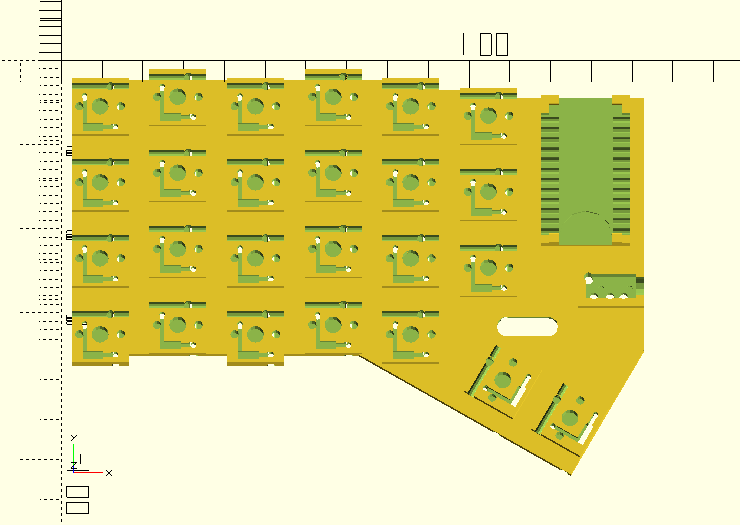
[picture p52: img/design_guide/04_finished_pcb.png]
Finished PCB


#### Plate Shaping (Optional)
By default, the plate profile is generated by using `hull()` and `offset()` on the PCB footprint. For rectangular layouts, this should be more or less sufficient, but if your layout has any concave areas (such as next to a thumb cluster), those will be filled in by the `hull()` operation. If all you need is a basic PCB, of you're fine with the basic plate generation, you can skip this section.

The primary mechanism for shaping the plate is the `base_plate_layout` variable. The layout format for each element is the same as everything else, where `extra_data` is a vector of the format `[component_type, extra_extra_data]`. `component_type` is selected from `["switch", "mcu", "trrs", "stab"]`, corresponding to what kind of element it is, and `extra_data` is any extra data you want passed down to the element's plate footprint module. `["switch"]` is the default, so you don't need to set it explicitly for those. However, instead of being a single vector of elements, `base_plate_layout` a vector of vectors of elements.

If `use_plate_layout_only = false`, then all the vectors are flattened, and added to the `hull()` that forms the case profile as described above. This can be useful if you just want to make your plate larger than the PCB in some dimension. Just remember that your single vector still needs to be wrapped in another vector.

If `use_plate_layout_only = true`, then things get interesting. Instead of using all the elements from `base_switch_layout`, `base_mcu_layout`, `base_trrs_layout`, and `base_plate_layout`, only the elements from `base_plate_layout` are used. And instead of a `hull()` over all the elements, each sub-vector has its elements hulled separately, and then all of these sub-plates are unioned before the offset is applied, allowing you to create concave forms. For the default layout, I union the thumb cluster keys separately from everything else. I also set the top border of the MCU to be -2, which has the effect of reducing the distance between the MCU connector and the edge of the plate.

Note that since only `base_plate_layout` is used in this mode, you need to copy all the components from the other component layouts in order for the complete plate to be generated. To make this easy, I've provided a `slice()` function to help copy over the relevant portions of those other layouts. See `default_layout.scad` for an example of its usage. The bounds support negative values, so you can index from the end of the array. You can set the end bound to `0` to indicate the end of the vector. In addition, an optional third parameter can be used to override any existing `extra_data` in the layout.

Where two sub-plates meet at an external vertex, the plate footprint can start to look weird if the corners of the sub-plates aren't close enough together. Here's an example:
<table style="border-collapse: collapse;">
<tr>
<td style="border: none; width: 30%;">
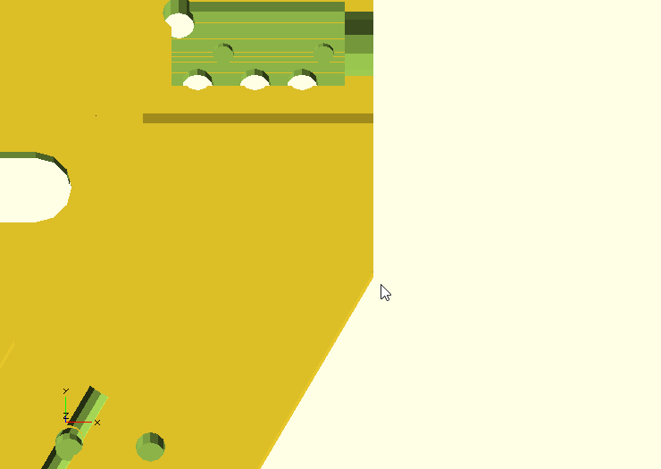
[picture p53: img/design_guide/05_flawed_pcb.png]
    
</td>
<td style="border: none; width: 30%;">
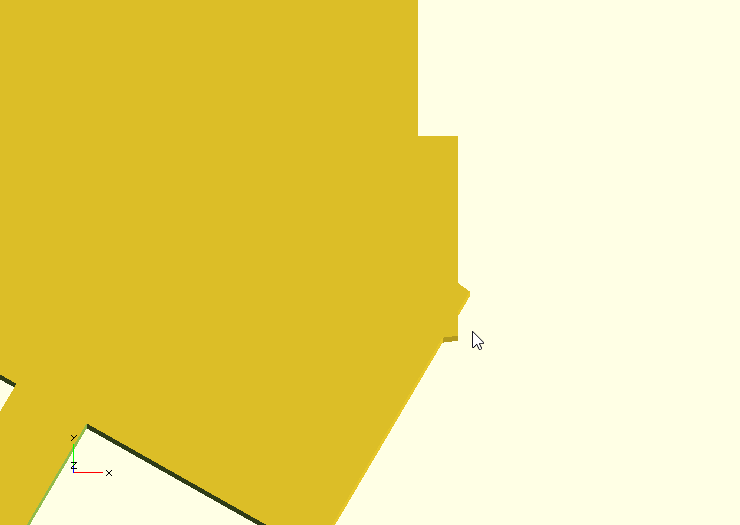
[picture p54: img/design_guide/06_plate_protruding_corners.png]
    
</td>
<td style="border: none; width: 30%;">
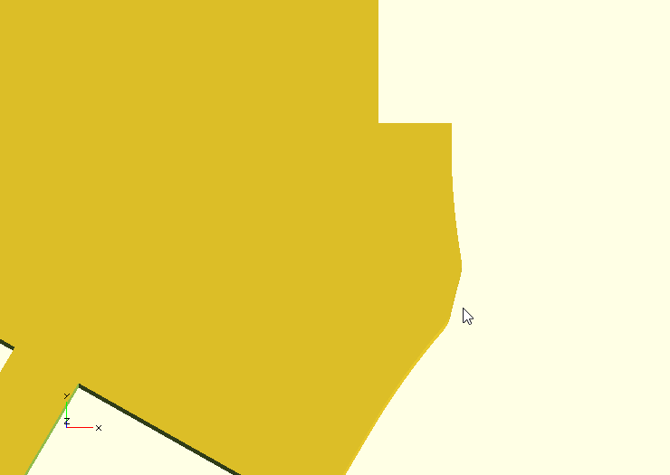
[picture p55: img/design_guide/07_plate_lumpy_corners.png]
    
</td>
</tr>
<tr>
<td style="border: none; width: 30%;">
    <p> Here we've changed the borders on the TRRS and thumb cluster a bit, but the PCB still looks fine... </p>
</td>
<td style="border: none; width: 30%;">
    <p> ... but when the offset is applied, the error at the corner is magnified because they are not actually the same point. </p>
</td>
<td style="border: none; width: 30%;">
    <p> When we apply the final rounding offset, the corner artifact manifests as a weird lumpiness in the corner. </p>
</td>
</tr>
</table>

It seems that OpenSCAD treats points within ~0.00003mm of each other as being the same, but it's not practical to get plate points within those kinds of tolerances, which starts to require some annoying trigonometry. To combat this issue, the `plate_precision` parameter is used to increase that merge tolerance to something more usable. For example, the default value of `0.01` requires you to get points within ~0.01mm away from each other before they merge. You can set this higher if you wish, but the downside is that this precision/rounding factor is applied to the entire plate outline, so excessively large values can cause your plate to become misshapen. Here's an extreme example, where `plate_precision = 5`:
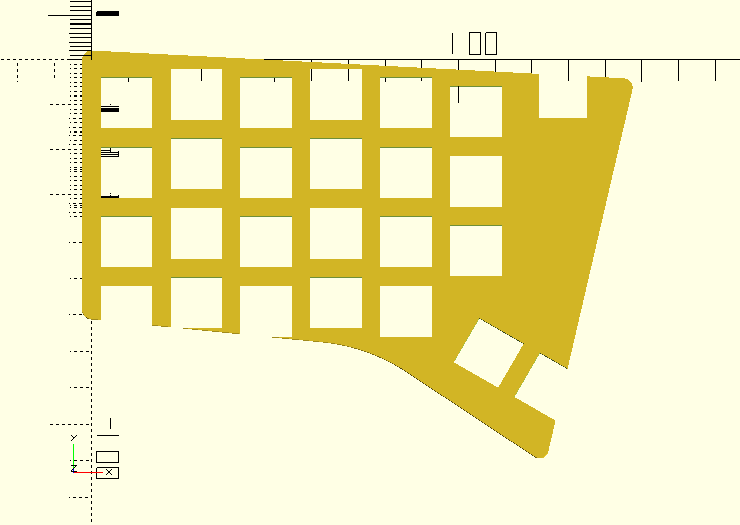
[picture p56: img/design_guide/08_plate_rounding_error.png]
Plate with rounding errors


I'm looking into other ways to fix this issue, but this is what we have for now.

In addition to the layout, there are some plate-related parameters in `parameters.scad`. `plate_margin` defines the total offset (in mm) from the PCB profile. I used 5 as the default, which is just wide enough to squeeze in a standoff or a case wall. `plate_outer_fillet` and `plate_inner_fillet` define the radius of the inner and outer fillets on the plate profile.

#### Standoff Placement
Standoffs are useful to keep the plate attached to the PCB without solely relying on the friction fit between the switches and the PCB. They can also be used to attach a backplate to the PCB-plate assembly if desired. Even if you're generating a case, you need standoffs to screw everything together. By default, the standoffs are designed for M2 screws to self-tap into the plastic, though there is an option to use separate brass standoffs.

Standoffs are placed using a layout vector, with `extra_data = [standoff_integration_override, standoff_attachment_override]`. `standoff_integration_override` defines which component the standoff is printed with, and is set to `"plate"` by default. `standoff_attachment_override` defines which component the standoff gets screwed into, and is `"pcb"` by default. In addition to standoffs, this will also generate screw holes and clearance holes in the PCB where standoffs between the plate and backplate can pass through. More details are available in the `scad/` README.

For the default layout I may have gone slightly overboard on the standoffs, but I wanted to make sure there was a secure hold between all the components:
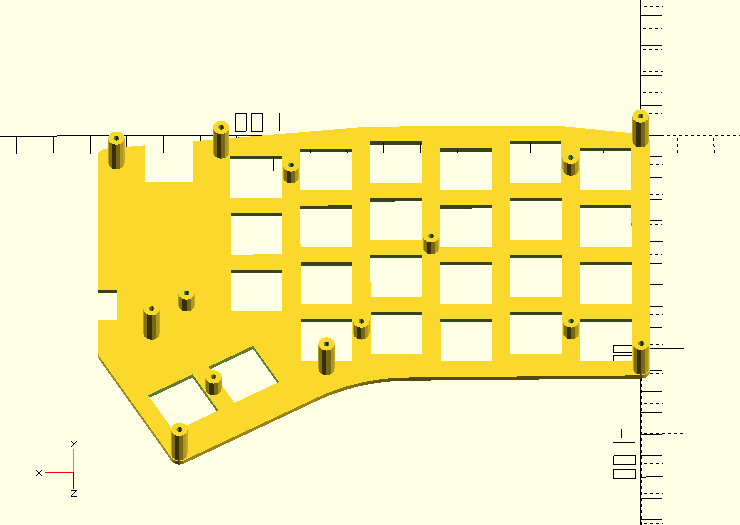
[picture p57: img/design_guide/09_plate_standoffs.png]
Plate with standoffs


#### Case Options
If you want something more solid, I recommend generating a case instead of just a plate-backplate sandwich. Case parameters are located in `parameters.scad`, and `case.scad` generates the actual case geometry, based on the plate geometry.

The first option is `case_type`, which can be selected from `["sandwich", "plate_case", "backplate_case"]`. `"sandwich"` is just a basic plate and backplate connected by standoffs, while `"plate_case"` is an integrated-plate case that screws into a backplate via the same standoffs. `"backplate_case"` is unimplemented, but is planned to be some kind of tray-mount construction.

`case_wall_thickness` is pretty self-explanatory, and I wouldn't recommend going below the default value of 2mm.

If `use_plate_layout_only = false`, your case profile is guaranteed to be convex, which unlocks the ability to use some cosmetic shaping options. `case_wall_draft_angle` makes the sides of the case angle outwards instead of going straight down, creating a wider base and some visual interest. `case_base_height` creates a vertical-walled portion at the bottom of the case below the drafted section. `case_chamfer_width` and `case_chamfer_angle` let you put a chamfer around the edge of the plate. Here's an example using the default layout:
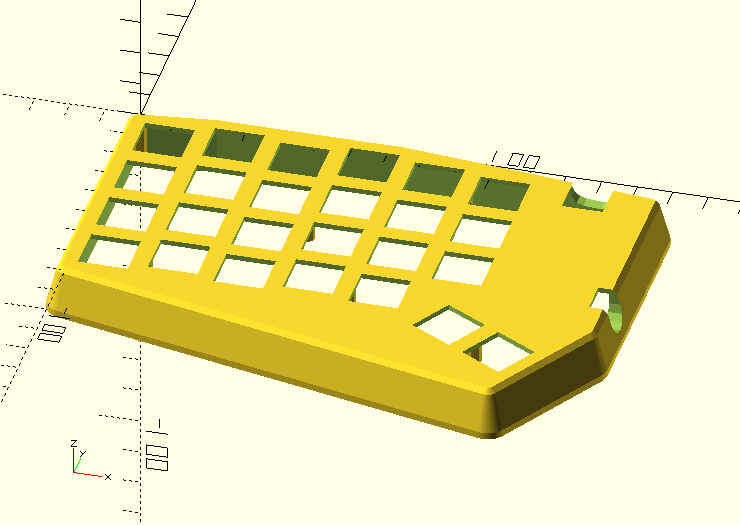
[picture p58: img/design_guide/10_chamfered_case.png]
Chamfered case


Finally, we have tenting options. Currently, tenting is implemented via the backplate, which can be swapped out to create different angles on the same case. `tent_angle_x` and `tent_angle_y` define the rotation around the respective axes, while `tent_point` defines the point that will stay at `z = 0`. You should put this near the bottom left of your case, so that no part of the case goes negative, as this will cause backplate generation to fail. For the default layout, I put the tent point at the bottom left corner of the main key cluster:
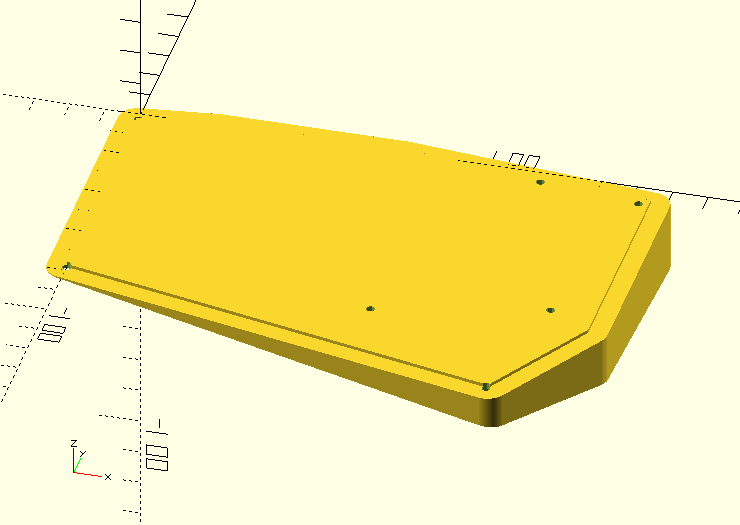
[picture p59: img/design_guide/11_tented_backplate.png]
Tented backplate


Here's what the case looks like assembled:
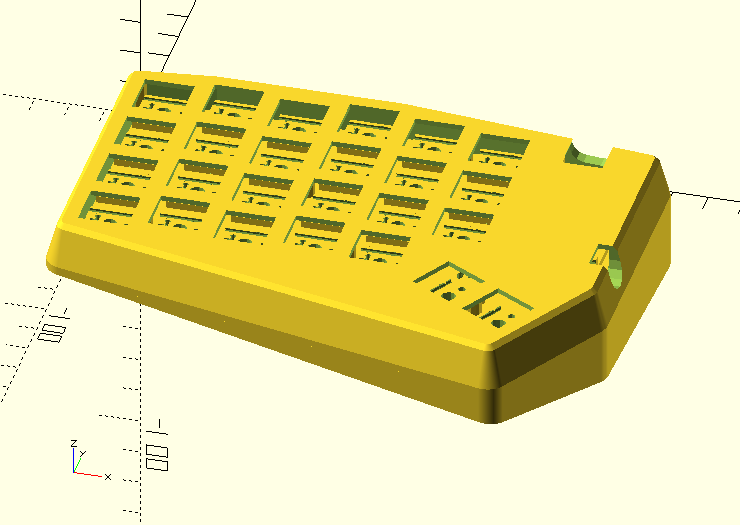
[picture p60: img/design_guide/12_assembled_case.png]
Assembled case


Now you should be ready to print! If you're working on a symmetrical split layout, you can simply set `invert_layout_flag = false` to generate all the files for the other side.

#### Advanced Options
There are a ton of other options you can play with that are all documented in the `scad/` README, but I'll just touch on a couple of them here.

The first two involve key spacing. By default, everything is set up to accommodate the standard 19.05mm key spacing that MX keycaps use. However, if you're using Choc or custom keycaps, you can decrease that spacing (within limits) by modifying the `unit`, `h_unit`, and/or `v_unit` variables in `parameters.scad`.

If you're using an MCU that's not Pro Micro-compatible, you'll need to break out your calipers and modify the MCU parameters in `parameters.scad` to fit your PCB.

If you're having trouble with flaky hotswap connections, you can try using the experimental `use_folded_contact` option, which will generate a slightly different socket and a new diode bending jig, but I don't have a tutorial for that one yet.

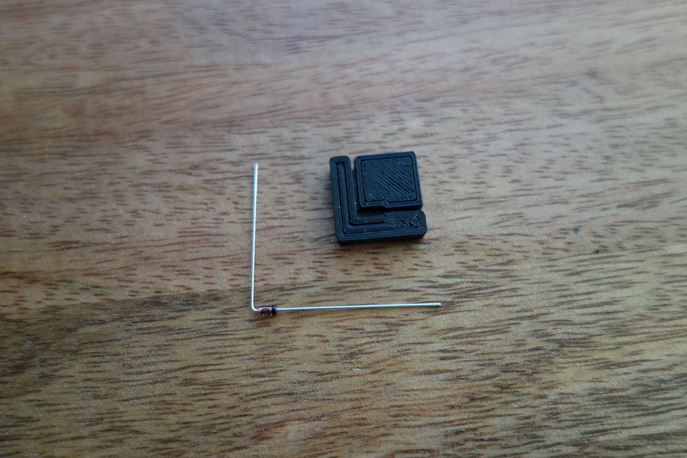
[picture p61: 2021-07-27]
img/build_guide/16_diode_bend_1.JPG

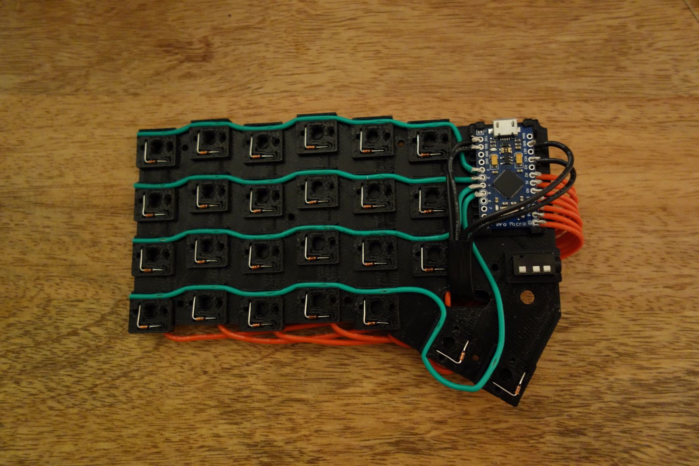
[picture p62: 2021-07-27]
img/build_guide/25_wiring_complete.JPG

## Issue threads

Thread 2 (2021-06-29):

Add MCU and TRRS socket holders

50an6xy06r6n, 2021-06-29:
A keyboard isn't complete without a microcontroller, and TRRS cables are often used to connect multiple keyboards (i.e. for split ergos). Would be nice to be able to add them to PCBs

50an6xy06r6n, 2021-06-29:
I have some ideas on how to implement this

50an6xy06r6n, 2021-07-02:
Basic functionality implemented in 2a2a175cc97f4faa62b700c4974ffedc2dffa808, but leaving this open for documentation and testing

50an6xy06r6n, 2021-07-26:
Documentation added via the build guide, so closing this

Closed 2021-07-26.

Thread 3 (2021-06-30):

Diode-less socket version

50an6xy06r6n, 2021-06-30:
If you're just testing a layout for basic key positions and you're not doing complicated chords, you can probably get away with not having diodes in your matrix. Since bending the diodes is one of the most time-consuming assembly steps, and you're liable to run out of them, it would be nice to have a version of the sockets that omits the diodes. This should be doable if the column wire runs under the bottom switch pin, passing through "vias" in the PCB to avoid collisions with the row wires.

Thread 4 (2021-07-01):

Switch key RGB light hole

AndyChiu, 2021-07-01:
Hi, is possible add RGB light hole? now have diodes on the way
if have light hole, maybe can add LED RGB strip light easy!

50an6xy06r6n, 2021-07-02:
do you mean holes for the LED wires, or just a through hole for the light to go through. Either way it will be tricky because the diode is in the way for the MX socket. I'll think about it, but since this is primarily intended for prototyping it doesn't seem like a critical feature.

AndyChiu, 2021-07-02:
Hi, just a through hole for the light to go through, i hope it will be used for a long time. If can added backplane, and add config standoff can pass through the PCB, and allow lock screw with the backplane, just like the sandwich structure, it will be used for a long time.

AndyChiu, 2021-07-31:
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
Hi, i try modify code to add LED cutout

                // Diode cathode cutout
                translate([3*grid,2.4*grid,0])
                    cylinder(h=pcb_thickness+1,r=.7,center=true);

                // Diode Channel
                translate([0,2.4*grid,pcb_thickness/2])
                    cube([6*grid,1,2],center=true);
                translate([.3*grid-.5,2.4*grid,pcb_thickness/2])
                    cube([4*grid,2,3],center=true);

                // Add LED cutout
                translate([0,-4*grid,pcb_thickness/2])
                    cube([5,4,10],center=true);

the Diode is more easy to install

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

renatosuero, 2022-02-03:
Hi, I'm new here, how is the led and the connection at the wire/diode?

AndyChiu, 2022-02-03:
Hi, I'm still think about how to connect , but i think use the LED  strip is be a easy way
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

slabua, 2022-04-29:
@AndyChiu Hi, do you have the individual stl for the mx switch with the led hole? I seem I can't find it in your fork, and not quite sure about how to generate it. Thank you.

slabua, 2022-04-29:
@AndyChiu I think I have figured it out. Please enable issues on your fork :)

AndyChiu, 2022-04-29:
hi, i was upload same stl file, and update my .scad, have fun! :)

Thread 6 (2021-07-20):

Add tenting support

50an6xy06r6n, 2021-07-20:
Would be nice to have the ability generate a tenting solution, either via an added base, or built-in to the backplate/standoff configuration somehow. Not exactly sure how to deal with the screws going in at an angle yet.

50an6xy06r6n, 2021-07-31:
Basic tenting added in 7a9dd94e194fa0ee8810427d27b547ccbdb82814. Have plans for other options so I'll keep this open

properlypurple, 2022-06-24:
It would be really cool to have support for something like this
https://www.thingiverse.com/thing:5259983

50an6xy06r6n, 2022-06-25:
Will look into it whenever I revisit this project

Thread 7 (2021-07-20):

Add support for solid cases

50an6xy06r6n, 2021-07-20:
I think integrated-plate cases are feasible, and could be a nice feature to have for more permanent solutions.

AndyChiu, 2021-07-21:
Hi, the generator is feasible create like this keyboard case ? have around wall
https://github.com/rtitmuss/torn/blob/master/case/HiPro%20Case/readme.md

50an6xy06r6n, 2021-07-22:
What I'm thinking is less complicated. Would probably be integrated with the plate or backplate

AndyChiu, 2021-07-22:
It's Great!

AndyChiu, 2021-07-22:
This have some idea
https://github.com/takjn/kbcgen

50an6xy06r6n, 2021-07-23:
Thanks, that gave me some ideas on how to make plate shape generation prettier overall.

50an6xy06r6n, 2021-07-26:
Started working on it in the [solid_case](https://github.com/50an6xy06r6n/hotswap_pcb_generator/tree/solid_case) branch

50an6xy06r6n, 2021-07-27:
Merged solid case code into main and added example STLs

Closed 2021-07-27.

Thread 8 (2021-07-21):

Add option to expose the MCU through the plate

50an6xy06r6n, 2021-07-21:
Could be useful if you want to be able to see the LEDs for status, or need access to pins for resetting, for example. Could also do some decorative mesh patterns in the plate.

50an6xy06r6n, 2021-07-28:
partially supported, but I don't like how it looks

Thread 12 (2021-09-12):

some components

AndyChiu, 2021-09-12:
Hi, i add some components and use UTP cable to create keyboard, i modified part of the file, and created another folders to separate, the folder name with '_UTP'
https://github.com/AndyChiu/hotswap_pcb_generator

50an6xy06r6n, 2021-09-27:
Hey sorry I've been pretty busy recently but I will try to take a look at the components you added. Particularly interested in the encoders. In general I think I need to find a nice modular way for people to add new components without major changes to existing code. Not sure exactly how to do that yet.

AndyChiu, 2021-09-27:
Hey, i was write a blog to show how to create keyboard with hotswap_pcb_generator, but now only chinese version
https://ie321mx.blogspot.com/2021/09/choc-v2.html
https://ie321mx.blogspot.com/2021/09/blog-post.html

aamott, 2024-02-27:
I know that this is old, but now that I see a few updates to this repo, I'll add my thoughts. AndyChiu's updates were very nice and I ended up using them for my prototyping, including the LED addition. Updated diode routing was the most helpful change. I'd love to see these features added here!

AndyChiu, 2024-02-27:
Thank you, I will be tidying up my code soon and updating it to my repo. Since I'm currently focusing on designing a curved keyboard, it has diverged a bit from this repository.

AndyChiu, 2024-03-03:
I've updated the repo, I tried to make the MCU more modular, and tried adding holder to the PCB to hold the switch.

https://twitter.com/andychiu/status/1748546787114369427

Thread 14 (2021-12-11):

How to generate case without hull like pcb does?

meteozond, 2021-12-11:
I want to make ymdk sp84  clone, but found that case is generated with hull, is it possible to override this behaviour?

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

50an6xy06r6n, 2021-12-11:
Check out the documentation for `base_plate_layout` and `use_plate_layout_only` in `scad/README.md`. There's an example of how to use them in `scad/default_layout.scad`.

Closed 2021-12-11.

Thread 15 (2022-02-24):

Question: Can this be used reasonably for making custom non-split boards?

KyleStiers, 2022-02-24:
Hello, I'm interested in using this to make a more standard layout (but still custom) board. I managed to get it installed and to render the correct layout as well as to remove the tent, as it's not a split board, but I can't figure out how to fine-tune the things you put in the design document. I'd like to add the MC and stabilizers and all that so I can test printing it, but any tips on that?

Do you just change the things in parameters.scad then re-render? The main struggle right now is adding the MCU and getting the whole board to be one pcb piece, as it currently splits it into a few pieces - I think due to spacing being more than some threshold. Also, is there any easy way to split this into two pieces when doing a more standard board like this? My 3d printer won't fit the whole thing, but I could maybe do that after everything else is done in Fusion or something.

I've attached the keyboard layout as a txt file as github isn't allowing JSON.

Thanks,
Kyle

[keyboard-layout.txt](https://github.com/50an6xy06r6n/hotswap_pcb_generator/files/8135474/keyboard-layout.txt)

KyleStiers, 2022-02-24:
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

Here is an image of the current keyboard.scad that is generated

AndyChiu, 2022-02-25:
Hi, you can try this file
[layout.scad.txt](https://github.com/50an6xy06r6n/hotswap_pcb_generator/files/8137629/layout.scad.txt)

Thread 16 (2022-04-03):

Backplate not generating correctly

internetrelative, 2022-04-03:
I'm trying to generate the backplate using the jd40 example but I'm not sure what's wrong it

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

[scad.zip](https://github.com/50an6xy06r6n/hotswap_pcb_generator/files/8405039/scad.zip)

AndyChiu, 2022-04-03:
Tenting?
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

internetrelative, 2022-04-03:
>
ah that solves it, sorry It's my first time with openscad. How do you generate screw points to mount the backplate to the case of the keyboard?

AndyChiu, 2022-04-04:
hi, you can read this guide, and find Standoff Placement part
https://github.com/50an6xy06r6n/hotswap_pcb_generator/blob/main/guide/design_guide.md

internetrelative, 2022-04-05:
I got it to work :) , didn't know I had to specify the location of the standout manually

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

[jd40_scad.zip](https://github.com/50an6xy06r6n/hotswap_pcb_generator/files/8420636/jd40_scad.zip)

Closed 2022-04-05.

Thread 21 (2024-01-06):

Previous commit completely broke switch/pcb generation

BlueDrink9, 2024-01-06:
Rendering default layout switch.scad and pcb.scad with 7f01171 creates something completely non-functional. I'm on openscad 2021.01 btw, in case it looks fine on your end

I presume from the commit message that this was an experimental change, but I spent ages trying to debug thinking it was some lingering change in my config. Would you consider doing experimental changes in a development branch, and leaving main more stable?

50an6xy06r6n, 2024-01-06:
Ah sorry about that. I changed some parameters to test something and forgot to change them back. If you change `pcb_thickness` to `4` and `pcb_type` to `printed` I think that should fix the issue.

In general I think this library could use some better pattern for managing parameters like that on a per-project basis, but I'll try to be more careful about committing changes to `parameters.scad`.

In terms of targeting changes on a different branch, I'm not sure this repo has enough activity to have a fully separate `develop` branch, as it is useful to have people report regressions caused by new features. I did go ahead and create a release for the previous stable version, so if you run into issues down the road you can try to revert to that.

I'll have a fix up for this shortly.

50an6xy06r6n, 2024-01-06:
@BlueDrink9 I just put up a new commit that I think should fix your issue (along with a bunch of other things I found).

After thinking about it some more, I will try to start putting incremental changes in a `develop` branch, and bring those into `main` after I've had time to test it a bit and make sure I didn't break basic model generation.

BlueDrink9, 2024-01-06:
Thanks! I'll PR my enhancements hopefully this week or so. I'll look at what could be shifted out of params as part of that, if you'd like?

Already built one very custom board with this, but it required a big bunch of tweaks in the main code so won't be adding it as an example. Starting on another board shortly, and I wanted to try address some of the issues I had with the switch connection

50an6xy06r6n, 2024-01-06:
I already have some thoughts on how to improve the modularity, so don't worry about putting that in your changes, since I'll probably override them 😛 But if you want to discuss via issues I'd be happy to engage.

I welcome any PRs you have for enhancements, but fair warning that I don't have much of a process figured out for how I incorporate external changes. I am curious what issues you had with the switch connections and what your solution was.

BTW would love to see pictures of the board you built! This project has been kind of sitting around for a couple years and I could tell people were using it, but I haven't seen much of what folks have actually made.

50an6xy06r6n, 2024-01-06:
Actually if you want to discuss, let's do it in https://github.com/50an6xy06r6n/hotswap_pcb_generator/issues/13, since I apparently realized this was an issue 2.5 years ago

BlueDrink9, 2024-01-06:
Yeah definitely have plans to post pics and tag you, I'm well aware that it feels good to see what people use your work for! Recent build though and I have some other stuff to get out first before I do the write-up though

BlueDrink9, 2024-01-07:
> @BlueDrink9 I just put up a new commit that I think should fix your issue (along with a bunch of other things I found). Let me know if you're still having issues.
>
> After thinking about it some more, I will try to start putting incremental changes in a `develop` branch, and bring those into `main` after I've had time to test it a bit and make sure I didn't break basic model generation.

Getting a new error now:
```
[WARNING: Ignoring unknown variable 'stab_2u' in file param_processing.scad, line 27]
[TRACE: called by 'set_defaults' in file param_processing.scad, line 27]
```

50an6xy06r6n, 2024-01-07:
Ah looks like I forgot to include the stabilizer presets file somewhere

On Sat, Jan 6, 2024, 7:21 PM Silico_Biomancer ***@***.***>
wrote:

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

BlueDrink9, 2024-01-07:
Fixed by adding include <stabilizer_spacing.scad> to default_layout.scad

50an6xy06r6n, 2024-01-08:
Ok pushed another change to include the presets in the appropriate places

santiagoluz, 2024-01-13:
I decide to build a custom keyboard and I was excited that I found this project. Then I started using it forthe first time and it wasn't generating the PCB the same way as described in the build buide. I thought I was doing something wrong. I came back to this yesterday and I realized there was an update to the repo. Thanks a lot for both of you, one for reporting it and the author for fixing (and building) it. :)

BlueDrink9, 2024-01-20:
@50an6xy06r6n is it intentional that the current default layout defines an empty layout? Currently if you open any of the files like pcb.scad or layout.scad, nothing is rendered.

50an6xy06r6n, 2024-01-20:
Yeah the default layout is now mostly there to define variables that might not be used so stuff doesn't break. Probably should change the name at some point

Closed 2024-01-08.

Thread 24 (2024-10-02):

How do these affect height / Please provide side view, or schematic

OWL4C, 2024-10-02:
Without building these, i wonder how much they affect the height of a keyswitch. Having made my case in ergogen already, i was hoping to add these to the wall height of my case, but  i do not know how much they change the height of the switch.

From a youtube video, i saw that they do not sit flush with the bottom of the switch, since the diode is between them. Maybe that was only the videos fault- i don't know.
It would be nice if you could take some pictures from the side and / or give some measurements (or ranges, if they can slide up and down).
Really nice would be the amount of space between the casing (lower edge without stem) to the upper pcb, since feet length can vary.
Since different sources have different feet length (between 2-3 mm for the contacts) and the pcb i created is 4mm thick, knowing how near they can get to the switch casing would be enough to plan my case.

50an6xy06r6n, 2024-10-03:
There's a YouTube video about this? That's news to me. Can you link it so I can see what gap you're referring to?

The PCB is designed so that the switches can sit flush when using the glass-encased variety of 1n4148 diodes. I have not tested it using any other diode types. Maybe that should go in the README if it isn't already.

OWL4C, 2024-10-03:
There was this 3 hour livestream which is really more about the youtuber chatting than the project.
https://www.youtube.com/watch?v=3ZCAY2VO7p8 At around 2:06 you can see the switch get inserted but because of the perspective i couldn't figure out if it is flush or slightly sitting on top of the diode. Looking at it one a bigger screen now you can reasonably suspect they sit flush though.

If they sit flush with the bottom housing, by my own measurements and this website https://media.digikey.com/pdf/Data%20Sheets/Cherry%20PDFs/MX%20Series.pdf you could mention that at 4mm they will increase the height by only .7mm; as for me, i'll just make the case 1mm higher, and the keys should still reach the pcb comfortably. I'll be sure to update this as soon as the print arrives and i can test out the fit!

OWL4C, 2024-11-24:
Okay i have tried multiple settings for a Creality Ender 3 V3 Se, but with a 0.4mm default nozzle and many different speeds, i still get unusable prints, without holes or indentations. Are there any recommendations for settings? Maybe even for a Ender Style printer?

50an6xy06r6n, 2024-12-06:
What do you mean without indentations? This sounds more like a print quality/possibly slicer issue tbh. I don't think the choice of printer really matters that much if it's dialed in (I printed mine off of a self-sourced Kossel mini with questionable calibration).

Also, as noted in the documentation, you can use a tiny drill bit and pin vise to open up holes that the printer doesn't print properly. It's tricky since the holes are sized for a snug fit, so you can't oversize them as much as you would for other applications.

50an6xy06r6n, 2024-12-06:
Would definitely recommend printing individual components to test calibration and stuff. Worst case, you can increase the hole sizing locally (I think most of those things are configurable in `parameters.scad`).

OWL4C, 2024-12-18:
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
this one is one of the best attempts. Besides the channels being clogged, which can easily be drilled, the top is also quite rough and melted, probably some temp problem?
The main issue is the missing holes for the switch pins, and the missing upper channel (non-diode leg). I am quite new to 3d printing and have no idea how to fix this, except use a .2 nozzle and more ventilation / cooling.

OWL4C, 2024-12-18:
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
Actually it seems like the mesh was broken from the start...
At least compared to the layout guides images.

AndyChiu, 2024-12-18:
Hello, could you please provide layout.scad and parameters.scad? This should provide a common basis for checking the problem.

50an6xy06r6n, 2024-12-18:
Yeah that model definitely doesn't look right. What does it look like in OpenSCAD? It looks like you're potentially combining some settings for row- and column-oriented layouts that aren't compatible.

On the fabrication side, it looks like your print has some pretty severe overextrusion, which would cause holes to be undersized and/or close up

OWL4C, 2024-12-18:
(One of) My layout: https://github.com/OWL4C/hotswap_pcb_generator/blob/main/l_layout.scad
And yes same geometry in scad:
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

50an6xy06r6n, 2024-12-18:
Hmm there's nothing obviously wrong with the layout there... I will have to take a look later

OWL4C, 2024-12-18:
Thanks a bunch! I'll make sure to push my entire working folder with all the files to that repo, maybe something else is wrong.

Closed 2024-10-03.

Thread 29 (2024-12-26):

Add support for Gateron KS-33 switches

50an6xy06r6n, 2024-12-26:
I got some KS-33s a while ago so I might as well add support for them in here

rossw42, 2025-06-30:
While I can get the pins to fit correctly - the col and row settings are now messed up, lots of manipulating to try and get them to fit right - I will clean up my switch.scad and share it in a few days.

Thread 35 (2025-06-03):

Right side of the stl

kndrckjvr, 2025-06-03:
I cannot figure out how to generate the right side of the pcb of the default layout would release the stl files for these too thanks!

kndrckjvr, 2025-06-03:
found it just need to change the flag to invert~

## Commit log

2021-06-15 Adding scad script to generate PCB with a custom default layout, as well as a quick node.js script to convert KLE layouts into vectors compatible with the script.
    [pcb.scad]
2021-06-15 Added experimental support for staggered-row layouts
    [pcb.scad]
2021-06-25 Changed the converter script to just generate an SCAD file that's included by `pcb.scad`, since OpenSCAD customizer doesn't support nested arrays.
    [default_layout.scad, pcb.scad]
2021-06-25 Updated README and some comment formatting
    [default_layout.scad]
2021-06-26 Renamed variables for clarity and made a top level pcb module
    [default_layout.scad, pcb.scad]
2021-06-27 Prettified script output and tweaked README more
    [pcb.scad]
2021-06-27 Refactored basic parameters into a separate file and added a diode bending template. Updated the README with detailed assembly instructions.
    [diode_bending_template.scad, parameters.scad, pcb.scad]
2021-06-27 Added plate.scad to generate basic plates, as well as integrated standoffs.
    [default_layout.scad, parameters.scad, pcb.scad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]
2021-06-27 Added support for Choc v1 switches and custom horizontal/vertical spacing.
    [default_layout.scad, diode_bending_template.scad, parameters.scad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]
2021-06-29 Refactored standoff code into its own file
    [default_layout.scad, parameters.scad, pcb.scad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]
2021-06-29 Restructured directories and added dedicated READMEs for each.
    [choc_diode_bending_template.stl, default_layout.scad, diode_bending_template.scad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]
2021-07-02 Added support for MCU and TRRS sockets, and refactored SCAD code
    [default_layout.scad, mcu.scad, parameters.scad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]
2021-07-04 Added backplate and refactored a bunch of standoff code to allow for individual overrides
    [backplate.scad, default_layout.scad, keyboard.scad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]
2021-07-05 Updated README to reflect new features and updated conversion script to work with new layout format. Also renamed some variables for consistency
    [backplate.scad, default_layout.scad, keyboard.scad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]
2021-07-13 Replaced kyria example with crkbd due to unauthorized use of the name (apologies to Thomas Baart) and restructured example_layouts directory to include applicable licenses.
    [crkbd.scad, eggcat.scad, jd40.scad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]
2021-07-16 Added support for "vias" to route wires through the PCB
    [default_layout.scad, parameters.scad, pcb.scad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]
2021-07-20 Added plate cutout for TRRS plug clearance
    [parameters.scad, trrs.scad]
2021-07-24 Added better plate profile generation and solid case construction
    [backplate.scad, case.scad, default_layout.scad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]
2021-07-24 Add convexity to linear_extrudes for nice rendering
    [case.scad, parameters.scad, plate.scad]
2021-07-24 Added documentation for new plate and case code
    [backplate.scad, default_layout.scad, keyboard.scad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]
2021-07-25 Updated documentation, conversion script, and examples to account for new case parameters
    [backplate.scad, crkbd.scad, default_layout.scad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]
2021-07-27 Added chamfering to case code. Restructured stl directory and added example output for the default layout.y
    [backplate.scad, backplate.stl, case.scad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]
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2021-07-28 Make diode switch contact folded for better reliability
    [diode_bending_template.scad, parameters.scad, switch.scad]
2021-07-28 Added stl for improved mx diode template
    [diode_bending_template.scad, mx_improved_diode_bending_template.stl, switch.scad]
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2021-07-28 Added documentation for stabilizers
    [default_layout.scad, parameters.scad]
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2021-07-29 Fix bug with backplate offset for slab-sided cases being too high
    [backplate.scad]
2021-07-31 Added tenting via interchangeable backplates
    [backplate.scad, default_layout.scad, grid_patterns.scad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]
2021-07-31 Added a picture of the tented case and generated STLs for default layout
    [backplate_tented.stl, default_layout.scad, parameters.scad]
2021-08-02 Added a design guide that covers how to convert a KLE layout into a full keyboard design.
    [crkbd.scad, default_layout.scad, eggcat.scad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]
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2023-12-12 Add experimental plate cutouts and plate layout trimming
    [case.scad, eggcat.scad, grid_cutout.scad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]
2024-01-06 Revert some layout-specific changes in shared files and refactor to improve modularity
    - Reverted layout-specific changes to `parameters.scad`
    - Replaced layout-specific MCU case cutout with configurable
    `additional_plate_cutouts` module
    - Refactored some utility functions to be usable in other files
    - Added the ability to remove small islands in grid cutouts
    - Add MCU grid cutout to standalone plate
    - Colorized full keyboard output
    - Moved parameter processing in `utils.scad` to its own file
    - Moved tenting parameters to `layout.scad`
    - Disambiguated grid cutout parameters name (cutout grid and MX switch
    schematic grid)
    [backplate.scad, case.scad, default_layout.scad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]
2024-01-06 Update documentation and move a couple more things
    - Move tenting parameters to `layout.scad`
    - Update KLE conversion script to include parameters moved to
    `layout.scad`
    - Update documentation to describe `trim` feature
    - Update documentation to reflect parameter restructuring
    [default_layout.scad, parameters.scad, utils.scad]
2024-01-06 Convert line breaks from CRLF to LF
    [backplate.scad, case.scad, crkbd.scad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]
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2024-01-20 Make 5 pin holes optional
    [parameters.scad, switch.scad]
2024-01-20 DRY some switch code
    [switch.scad]
2024-01-20 More DRY on wire channels
    [parameters.scad, switch.scad]
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2024-01-20 Use teardrops for wire channels
    [param_processing.scad, switch.scad, teardrop.scad]
2024-01-20 Unify choc and mx socket cutouts
    [switch.scad]
2024-01-20 Column wire crosses top pin at an angle to improve contact
    [parameters.scad, skew.scad, switch.scad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]
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2024-01-20 Refactor kink code and fix distances
    [switch.scad]
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2024-01-20 Fix kink with row-staggered layout
    [parameters.scad, switch.scad]
2024-01-20 Fix missing top switch pin hole
    [switch.scad]
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2024-01-20 Fix choc side pins not generating
    [switch.scad]
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2024-02-03 Advise against crossing diode wires
    Realised this when making my board, when I had ROW2COL/COL2ROW the wrong way
    around in firmware, and half my keys didn't work (or so I thought -
    actually none of them should have). The keys that worked were being
    shorted by the crossed diodes.
    This is a subtle mistake, because you won't notice it unless you're a
    furious typer, but it defeats the point of having diodes and can lead to
    ghosting when multiple keys are pressed at the same time.
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2024-12-26 Implement chamfering for concave case profiles (e.g. plate-layout cases)
    [backplate.scad, case.scad, parameters.scad]
2024-12-26 Add fillets to the bases of standoffs to improve strength
    [parameters.scad, standoff.scad, switch.scad]
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2024-12-27 Add support for sharp and beveled corners for chamfers and drafts
    [case.scad, parameters.scad, plate.scad]
2024-12-28 Various tweaks and improvements to case generation
    - Some refactors to improve code reuse
    - Fixed an issue that made it possible for the PCB to intersect the
    case. Automatically adds a PCB-shaped cutout if the wall thickness is
    set too high relative to the plate offset. (see `case_min_pcb_clearance`)
    - Added the ability to add extra internal cutouts via
    `additional_case_cavities`
    - Apply trim values to PCBs in addition to cases
    - Tweaked some default values
    [case.scad, default_layout.scad, eggcat.scad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]
2025-01-02 Use case cavity outline for backplate indexing feature
    [backplate.scad, case.scad, parameters.scad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]
2025-01-02 Add ability to specify cutouts on the bottom of the backplate
    - Can be used to add recesses for bumpons or attachment points for
    mounting
    - Accounts for tenting geometry
    - Also refactored a bunch of inconsistent positioning logic to be easier
    to work with (and fixed some associated bugs)
    - Updated eggcat example layout to take advantage of new features
    [backplate.scad, default_layout.scad, eggcat.scad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]
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
